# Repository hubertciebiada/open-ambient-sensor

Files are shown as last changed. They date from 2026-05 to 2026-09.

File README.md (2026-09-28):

<h1 align="center">OAS — Open Ambient Sensor</h1>

<p align="center">
  <b>DIY multi-sensor environmental monitor for indoor spaces.</b><br>
  Measures air quality and presence; mounts on a standard wall-recessed electrical box; runs ESPHome and integrates natively with Home Assistant.
</p>

<p align="center">
  
  
  
  
  
</p>

https://github.com/user-attachments/assets/d60150c3-3ed5-4fff-b437-b9b54c48e413

<p align="center">
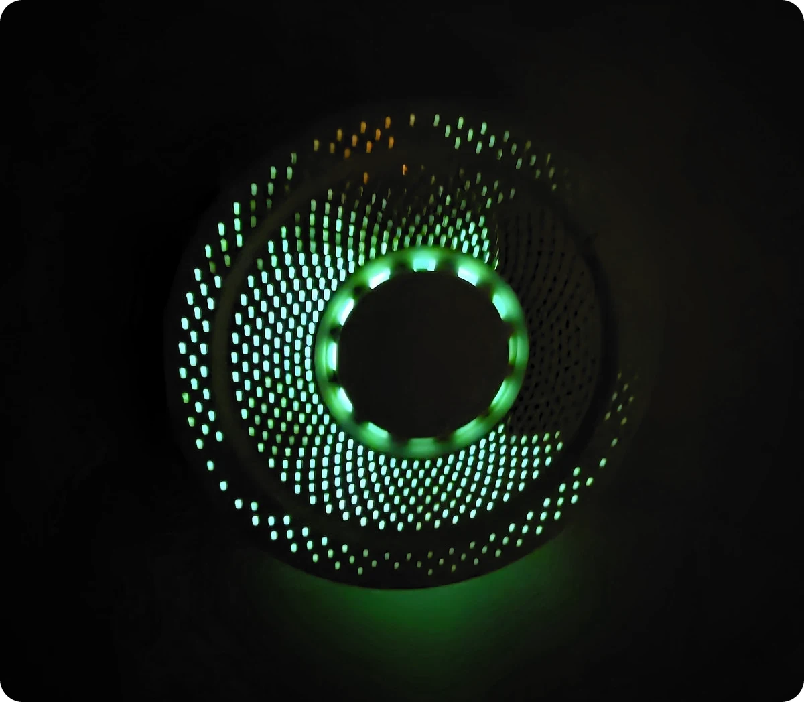
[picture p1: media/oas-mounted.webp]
OAS mounted on a wall in the dark: the AQI ring glows green through the perforated AK-N-94 cover
  
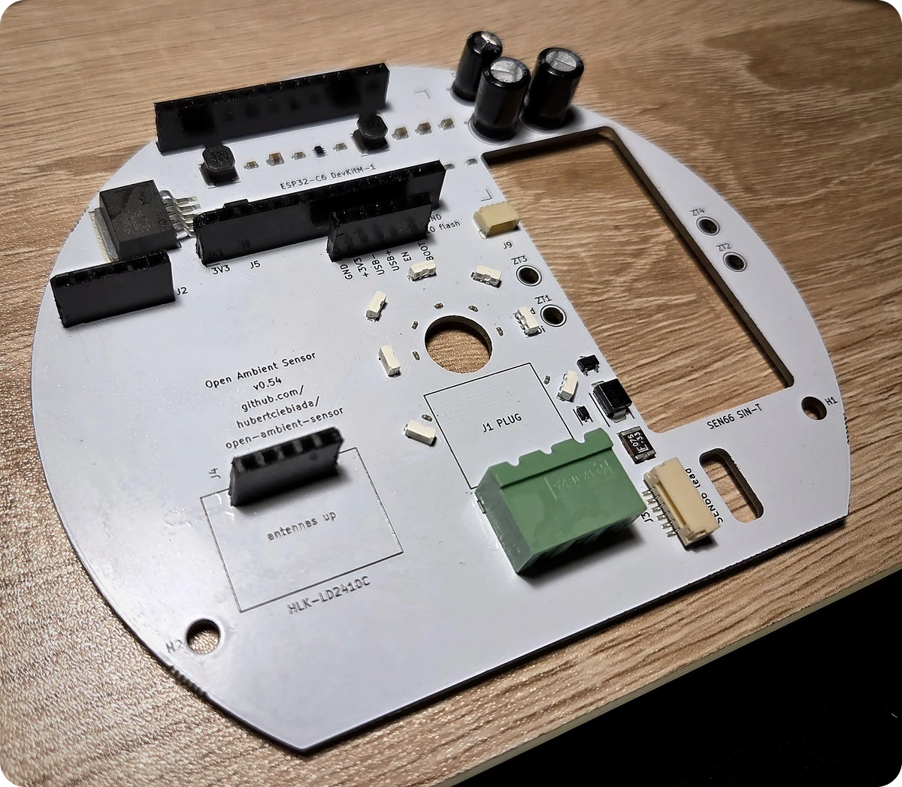
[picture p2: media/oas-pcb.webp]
OAS v0.54 PCB after SMT assembly, THT parts hand-soldered, daughterboards not yet fitted
  
</p>

---

## Status

**v0.54 — manufactured, bench-validated and in use.** Boards of this revision were fabricated and SMT-assembled at JLCPCB, brought up on the bench with a repeatable per-unit check, and run in a multi-unit deployment as the sensor input for Home Assistant HVAC automations. Working on the delivered hardware: the 24 V power chain, the Sensirion SEN66 (CO₂ / PM / VOC / NOx / T / RH, with Sensirion's STAR temperature compensation running inside the module), the HLK-LD2410C presence radar including stillness detection, the LED ring, Wi-Fi / OTA / native Home Assistant API, the Bluetooth proxy and the on-device web dashboard. The firmware reports `project_version: v0.54`, matching the version printed on the silkscreen. The design is fully script-generated and verified: `build.py` 35/35 stages PASS, DRC 0 violations / 0 unconnected, JLCPCB DFM 0 Danger on both the bare-board and assembly checks. The production files for this revision are attached to the [GitHub release](https://github.com/hubertciebiada/open-ambient-sensor/releases). See [`CLAUDE.md`](./CLAUDE.md) for the design rationale, hard constraints and the lessons learned along the way.

---

## Can I build one today?

**Yes — this revision has been built and works.** What to know before ordering:

- **The production files are in the repo.** [`hardware/output/jlcpcb/`](./hardware/output/jlcpcb/) holds the gerber + drill bundle, the BOM and the CPL files for JLCPCB SMT assembly (also attached to the GitHub release); they are regenerated and verified by the 35-stage pipeline on every build. Follow the ordering workflow in [`CLAUDE.md`](./CLAUDE.md#jlcpcb-ordering-workflow-distilled-from-v040-saga) — in particular the pre-payment Assembly Order cross-check, which has caught wrong-part substitutions more than once.
- **Seven components are hand-soldered after assembly** — the 24 V terminal block, the two ESP32-C6-DevKitM-1 socket headers, the LD2410C header and the three THT capacitors — and the SEN66 is attached with its JST GH lead and zip ties. Flashing and Home Assistant onboarding are documented in [`firmware/README.md`](./firmware/README.md).
- **Cost positioning.** OAS deliberately sits above bargain-DIY BOM cost: a calibrated Sensirion SEN66 combo sensor, an mmWave radar with stillness detection, and a commercial-grade injection-moulded enclosure are all premium choices made on purpose — see [Design philosophy](#design-philosophy). If lowest possible cost is your priority, other open-source projects optimise for that instead.

**Known limitations** (findings on the built units):

- **The LED ring effect is weaker than designed.** For the SEN66 to read correctly inside the enclosure, an air duct has to guide room air from the perforated cover to the sensor inlet, and that duct sits in front of part of the ring. The duct is not part of this repository yet.
- **Detecting a sleeping person relies on the presence timeout**, not on the radar's still-target thresholds — see the notes in [`firmware/esphome/packages/presence.yaml`](./firmware/esphome/packages/presence.yaml).
- **v0.51 prototype boards** need the pin overrides in [`firmware/esphome/HARDWARE-COMPAT-v0.51.md`](./firmware/esphome/HARDWARE-COMPAT-v0.51.md); v0.54 boards run the firmware defaults.

A consolidated step-by-step build guide is not written yet; open work is tracked in the [TODO list](./CLAUDE.md#open-work--todo) in `CLAUDE.md`.

---

## What it measures

- **Air quality** — CO₂, PM1 / PM2.5 / PM4 / PM10, VOC index, NOx index, temperature, relative humidity (Sensirion SEN66)
- **Occupancy / presence** — mmWave radar with stillness detection (HiLink HLK-LD2410C)

## Additional features

- 7× SK6812-SIDE RGB AQI ring with breathing effect (7 LEDs on an 8-slot ring; D13 vacated for the J1 24 V terminal); colour reflects an aggregated air-quality index
- **Bluetooth proxy** — extends BLE range across the deployment for Home Assistant BLE integrations
- Qwiic / STEMMA QT expansion port — future sensors without a PCB respin

---

## Design philosophy

The open-source DIY space offers many indoor-air-quality projects. Most optimise aggressively for cost. **OAS holds two priorities non-negotiable**, even when the trade-off is a higher per-unit BOM than the cheapest alternatives:

1. **Measurement quality.** Sensor choices favour accuracy and long-term stability over price.
2. **Aesthetic acceptability.** The device is meant to live in inhabited rooms; a commercial-grade injection-moulded enclosure replaces the typical 3D-printed box.

Both compromises (cheap-but-inaccurate, accurate-but-ugly) are rejected. See [`CLAUDE.md`](./CLAUDE.md) for the full rationale and the hard constraints any change must clear.

---

## Hardware overview

| Function | Component | Interface |
|---|---|---|
| MCU | ESP32-C6-DevKitM-1-N4 (EAN 5904422385651) | 2× USB-C on module |
| Air quality combo | Sensirion SEN66-SIN-T | I²C (JST GH 6-pin cable) |
| Presence | HiLink HLK-LD2410C | UART @ 256000 baud |
| Visual indicator | 7× SK6812-SIDE side-emit ring (Ø26 mm base pitch, 8 slots with D13 vacated for J1) | 1-wire WS281x on GPIO 8 |
| Power input | 24 V DC terminal block + TVS + PTC + reverse-polarity P-FET | — |

**Enclosure:** SZOMK AK-N-94 (Ø128 mm perforated white ABS). PCB is a **Ø120 mm D-shape** with a flat chord along the bottom edge. Mounts on a standard wall-recessed electrical box (60 mm screw pitch).

Authoritative module metadata (EAN, MPN, datasheet URLs, derived dimensions) lives in [`hardware/kicad/boardgen/_project.py::EXTERNAL_MODULES`](./hardware/kicad/boardgen/_project.py). Pinout is in [`boardgen/_project.py::GPIO_ASSIGNMENTS`](./hardware/kicad/boardgen/_project.py). Full design rationale and hard constraints: [`CLAUDE.md`](./CLAUDE.md).

---

## Repository layout

```
open-ambient-sensor/
├── README.md                       # this file
├── CLAUDE.md                       # design rationale, hard constraints, working conventions
├── GPLv3-LICENSE.md
├── .gitignore
├── media/                          # promo video (oas-promo.mp4) + README photos (oas-*.webp)
├── firmware/
│   ├── README.md                   # flashing + Home Assistant integration
│   ├── esphome/
│   │   ├── oas.yaml                # top-level ESPHome config
│   │   ├── packages/               # core / leds / air-quality / presence / bt-proxy
│   │   └── examples/               # anonymized per-device override examples
│   ├── tools/                      # bringup_check.py — repeatable per-unit bench check
│   └── secrets.yaml.example
└── hardware/
    ├── kicad/
    │   ├── build.py                # THE single entrypoint — emits sources + runs the 35-stage pipeline
    │   ├── boardgen/               # source of truth — generators for every .kicad_* file
    │   ├── pipeline/               # 35 verification/export stages (generic / oas / jlcpcb)
    │   ├── tests/                  # unit-test suite (pytest; run by stage 16 of build.py)
    │   ├── tools/                  # manual-trigger scripts (route extract, DFM upload, jlcparts cache)
    │   ├── oas_routes.py           # routing snapshot (replayed onto the generated PCB)
    │   ├── lcsc_mapping.py         # SMD BOM — LCSC SKU source of truth
    │   └── oas.kicad_*             # generated KiCad project files (derived artefacts — never hand-edit)
    ├── renders/                    # generated previews (PNG + SVG, visual changelog)
    ├── photos/                     # photos of built units (EXIF stripped)
    └── output/                     # production deliverables (ibom + jlcpcb/ ZIP + BOM + 2× CPL)
```

---

## Rebuilding the design from source

The KiCad project is **fully script-generated**. The `.kicad_pcb` / `.kicad_sch` / `.kicad_pro` / library files are derived artefacts — **never hand-edit them**; the next build overwrites every edit. The source of truth lives in [`hardware/kicad/boardgen/`](./hardware/kicad/boardgen/) (Python generators), [`lcsc_mapping.py`](./hardware/kicad/lcsc_mapping.py) (SMD BOM), and [`oas_routes.py`](./hardware/kicad/oas_routes.py) (routing snapshot).

```sh
cd hardware/kicad
python build.py
```

`build.py` is the only top-level entrypoint. It regenerates every KiCad source file bit-identically (deterministic v5 UUIDs — an unchanged tree produces an empty `git diff`) and then runs the full 35-stage verification pipeline: DRC, ERC, determinism self-check, analytical DC / ampacity / boot-strap / thermal / I²C-rise-time checks, ngspice SPICE simulations (buck soft-start, IEC 61000-4-5 surge, reverse polarity), unit tests, renders, and the vendor export stages that produce the JLCPCB deliverables. Any stage failure aborts the build.

**Requirements:**

- Python 3.11+
- KiCad 10 with `kicad-cli` on `PATH`
- `pip install mypy pytest cairosvg pygerber`
- `git submodule update --init` (kicad-skip, InteractiveHtmlBom, jlcparts, and other tools under `hardware/kicad/third_party/`)
- One-time jlcparts offline cache for the LCSC part-verification stage: `python hardware/kicad/tools/setup_jlcparts_cache.py` (~2 GiB download, expands to a local SQLite cache)

ngspice and the vendor SPICE models are downloaded automatically into a gitignored `.tmp/` directory on first run. Individual pipeline stages are independently runnable for debugging (e.g. `python pipeline/generic/03_drc.py`), but a committable state always comes from a full `build.py` pass.

---

## Contributing

Contributions are welcome once the design stabilises. Any change must clear both design pillars (measurement quality, aesthetic acceptability) and the hard constraints listed in [`CLAUDE.md`](./CLAUDE.md#hard-constraints-do-not-violate-without-an-explicit-documented-decision).

**This is a public repository** — see the [public-repository rules](./CLAUDE.md#-public-repository-rules) for the anonymisation and third-party-IP requirements that apply to every committed file.

---

## License

GNU General Public License v3.0 — see [`GPLv3-LICENSE.md`](./GPLv3-LICENSE.md).

---

## References

- AirGradient ONE (open-source inspiration): <https://github.com/airgradienthq/arduino>
- Sensirion SEN66 product page: <https://sensirion.com/products/catalog/SEN66>
- HiLink LD2410 documentation: <https://www.hlktech.net>
- ESPHome documentation: <https://esphome.io>
- JLCPCB component library: <https://jlcpcb.com/parts>

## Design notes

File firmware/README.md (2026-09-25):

# Firmware — ESPHome

OAS runs on **ESPHome** (YAML configuration) and integrates with Home Assistant via the native ESPHome API.

Hardware target: **ESP32-C6-DevKitM-1-N4** (ESP32-C6-MINI-1 SoM, 4 MB flash) on the OAS v0.54 PCB (v0.51 prototype boards need the pin overrides in [`esphome/HARDWARE-COMPAT-v0.51.md`](./esphome/HARDWARE-COMPAT-v0.51.md)). Framework: **esp-idf** (required for BLE proxy memory headroom — `arduino` runs out of IRAM with the C6 + BLE + WiFi + sensors all enabled).

## Layout

```
firmware/
├── esphome/
│   ├── oas.yaml             # top-level config, per-device substitutions
│   ├── packages/
│   │   ├── core.yaml        # WiFi, AP fallback, API, OTA, web_server, time, logger
│   │   ├── oas-dashboard.js # on-device dashboard: foldable cards, settings start folded
│   │   ├── leds.yaml        # SK6812-SIDE AQI ring (7 LEDs on GPIO 8; 8-slot ring with D13 vacated for J1)
│   │   ├── air-quality.yaml # Sensirion SEN66 (I²C 0x6B)
│   │   ├── presence.yaml    # HiLink LD2410 (UART @ 256000 baud)
│   │   └── bt-proxy.yaml    # Bluetooth proxy for Home Assistant
│   └── examples/            # anonymized per-device override examples
├── secrets.yaml.example     # template; copy to secrets.yaml (gitignored)
└── README.md                # this file
```

## Quick start

### 1. Install ESPHome

```bash
pip install esphome
```

Or use the Home Assistant ESPHome add-on, or the [ESPHome web flasher](https://web.esphome.io/) for first flash without a CLI.

### 2. Prepare secrets

```bash
cp firmware/secrets.yaml.example firmware/esphome/secrets.yaml
```

Edit `firmware/esphome/secrets.yaml` and fill in:

- `wifi_ssid` / `wifi_password` — your LAN credentials
- `ap_password` — fallback hotspot password (min 8 chars)
- `api_encryption_key` — generate with `openssl rand -base64 32` (paste the result as the `api_encryption_key` value in `secrets.yaml`)
- `ota_password` — any strong password

`secrets.yaml` is gitignored and must never be committed.

### 3. Set per-device identity

Each physical OAS unit needs a unique `device_id` and `friendly_name`. You have three options:

**Option A — Edit substitutions in `oas.yaml` directly** (fine for a single prototype):

```yaml
substitutions:
  device_id: livingroom
  friendly_name: "Living Room"
```

**Option B — Copy `oas.yaml` to a per-device file** (better for fleets):

```bash
cp firmware/esphome/oas.yaml firmware/esphome/devices/livingroom.yaml
# edit substitutions at the top
esphome run firmware/esphome/devices/livingroom.yaml
```

**Option C — Use the ESPHome dashboard** (Home Assistant add-on): each device gets its own per-device YAML in the dashboard UI; substitutions are editable from the web interface.

### 4. Validate the config (recommended before first flash)

```bash
esphome config firmware/esphome/oas.yaml
```

This catches typos and missing secrets without touching the device.

### 5. First flash (over USB-C)

The ESP32-C6-DevKitM-1-N4 has **two USB-C ports** (labels as printed on the DevKit silkscreen; bench-confirmed on the v0.54 bring-up):

- The port labelled **USB** is the ESP32-C6's native USB-Serial-JTAG (GPIO 12/13). It enumerates as `USB VID:PID=303A:1001`, needs no driver on modern Linux/macOS/Windows, and is where the firmware logger writes (`logger: hardware_uart: USB_SERIAL_JTAG`) — **use this port for logs and for the bring-up check below**.
- The port labelled **UART** goes through the onboard CP2102N USB-UART bridge (Silicon Labs CP210x driver). It flashes fine too, but carries no firmware log.

Either port flashes. Plug in and run:

```bash
esphome run firmware/esphome/oas.yaml
```

ESPHome auto-detects the serial port. Pick it from the menu if prompted.

Alternative for first flash without a local Python install: open <https://web.esphome.io/> in Chrome/Edge, click "Connect", select the OAS device, and upload the compiled `.bin` ESPHome produced. The web flasher uses WebSerial — no driver install needed.

### 6. After first flash

Once the device is on your WiFi, the on-device web dashboard is reachable at:

- `http://oas-<device_id>.local/` (mDNS — works on most modern OSes)
- `http://<device-ip>/` (find the IP in your router admin or in Home Assistant)

The dashboard is **web_server v3** (modern post-2024 ESPHome UI) and supports:

- Live sensor readings (CO2, PM, VOC, NOx, temperature, humidity, presence)
- LED ring controls (on/off, mode, brightness 1-10, night mode with its own brightness and hours, and a status line saying what the ring is doing)
- Number entity sliders to adjust sensor calibration offsets in real time
- Foldable cards: the ones holding settings start folded, so scrolling on a phone cannot drag a slider (see [On-device dashboard layout](#on-device-dashboard-layout))
- Live log viewer
- Read-only Prometheus metrics endpoint at `/metrics` for scraping

All of this works without Home Assistant — useful for first-bringup verification.

### 7. Home Assistant integration

Home Assistant should auto-discover the device via mDNS within ~30 seconds of it joining the LAN. If it doesn't, add it manually:

- **Settings → Devices & Services → Add Integration → ESPHome**
- Host: `oas-<device_id>.local` (or the IP)
- Encryption key: paste the `api_encryption_key` from your `secrets.yaml`

After the initial pairing, all further updates flow over the air via the ESPHome dashboard inside Home Assistant.

### 8. Subsequent updates (OTA)

Once a device is on the network, you don't need USB any more. From any machine on the same LAN:

```bash
esphome run firmware/esphome/oas.yaml --device oas-<device_id>.local
```

Or just press "Update" in the Home Assistant ESPHome dashboard.

**Leave the unit powered for at least a minute after an OTA update.** The firmware runs from two OTA slots with ESP-IDF app rollback enabled: the freshly written app only becomes the permanent choice once it has booted cleanly, and a reset or power cut before that hands the next boot back to the previous firmware — "OTA successful" in the upload log notwithstanding. Bench-confirmed on the v0.54 bring-up (a reset ~30 s after OTA rolled back; the same image left alone for 95 s then booted from the new slot and survived a reset).

## Bench bring-up check (repeatable per unit)

`firmware/tools/bringup_check.py` turns "flash it and look at the log" into one command with a PASS/FAIL table, so every assembled board gets the same inspection:

```bash
python firmware/tools/bringup_check.py firmware/esphome/devices/<unit>.yaml
```

Connect the unit to 24 V and the DevKit's **USB** port, then run it. The script finds the port, runs `esphome run` (compiles if needed, flashes), pulses a reset and reads the boot log (ESPHome / project version, SEN66 serial + firmware, STAR preset upload, WiFi, no errors or reboot loop), resolves the unit over mDNS, and reads the web dashboard's event stream to check the live entities: SEN66 readings in sane windows, LD2410 UART alive (distance sensors + baud), the OUT-pin entity, ring, BLE proxy, RSSI. It prints the WiFi MAC + IP (reserve them in DHCP before the unit moves to its room) and writes the full report under `devices/reports/` (gitignored). `--no-flash` re-checks a running unit; `--ip` is the fallback when mDNS does not cross your VLANs.

Note for the bench: until a unit is paired with Home Assistant, `api.reboot_timeout` (15 min) restarts it every 15 minutes with `[E][api]: No clients; rebooting` — expected, and the check ignores that line.

## First-time WiFi provisioning without secrets.yaml

If you don't want to write WiFi credentials into `secrets.yaml` before first flash (e.g. for a unit you're shipping to someone else), the `core.yaml` package enables **Improv Serial**:

1. Flash the device once with placeholder WiFi credentials (any string).
2. Plug it into a host running Chrome/Edge.
3. Visit <https://www.improv-wifi.com/>, click "Connect", select the device.
4. Enter the target SSID + password — the device commits them to flash and reboots onto WiFi.

Alternatively, the **AP fallback** (`OAS-<device_id>-Setup` SSID, gated by `ap_password`) and **captive portal** combination lets a phone connect to the device's own hotspot and re-enter credentials through a web form.

## Troubleshooting

| Symptom | Likely cause |
|---|---|
| Device doesn't show up on mDNS | Most consumer routers block mDNS across VLANs. Find the IP via your router admin and use `http://<ip>/` directly. |
| `secrets.yaml not found` | The file lives next to `oas.yaml`, i.e. `firmware/esphome/secrets.yaml`, not at the repo root. |
| `Could not find file '…/firmware/packages/oas-dashboard.js'` | ESPHome older than 2026.9 compiling `oas.yaml` directly: before 2026.9 a package's file paths resolve only relative to the main config, and the path in `core.yaml` is written for a config one level down (`devices/`, `examples/`). Update ESPHome, or compile through a per-device file in `devices/`. |
| OTA fails with "wrong password" | Re-flash via USB-C with the new password baked in. Lost OTA passwords cannot be recovered. |
| LED ring doesn't light | Check that `+5V` is reaching the LM2596S output — `core.yaml` itself never touches the LED ring; that's `leds.yaml`'s job. |
| SEN66 measurements stuck on "unavailable" | Likely I²C bus issue; scan with `i2c.scan: true` (already enabled). SEN66 lives at 0x6B. |
| Presence flips on/off every few seconds in an empty room | Gate 0 (0-0.75 m) picking up the SEN66 fan / cover from inside the enclosure on the factory threshold (moving energy 51-55 vs 50, reported distance ~30 cm). Set `G0 Move Threshold` to 100 (`bringup_check.py` does it on every unit), then press `LD2410 Read Params` to confirm the radar stored it. |
| LD2410 presence never triggers | Verify UART pins (TX=GPIO1, RX=GPIO0 — they moved off GPIO16/17, see CLAUDE.md Lesson 23) and 256000 baud rate. Use `logger: VERBOSE` to see the raw protocol. |

## Status

**Firmware v0.54 — running on the v0.54 boards (5 packages):** `core.yaml`, `leds.yaml`, `air-quality.yaml`, `presence.yaml`, `bt-proxy.yaml`. Bench-validated on delivered hardware: SEN66 readings with Sensirion's STAR temperature compensation inside the module, LD2410C presence over UART (per-gate thresholds, gate 0 disabled, the radar's Bluetooth kept off), LED ring, OTA through the Home Assistant ESPHome add-on, native API discovery, Bluetooth proxy. `project_version` follows the board silkscreen (`v0.54`). `tools/bringup_check.py` is the repeatable per-unit bench check. The dynamic NFC tag package was removed together with the NFC hardware (GitHub issue #7).

---

## Home Assistant integration

### Exposed entities

#### Sensors (`sensor.*`)

| Entity (suffix) | Unit | Source |
|---|---|---|
| `co2` | ppm | SEN66 (NDIR, 400-40 000 ppm) |
| `pm1` / `pm2_5` / `pm4` / `pm10` | µg/m³ | SEN66 (laser scatter) |
| `voc_index` | (1-500) | SEN66 MOX (Sensirion VOC index, 100 = baseline) |
| `nox_index` | (1-500) | SEN66 MOX (1 = baseline) |
| `temperature` | °C | SEN66 SHT4x (STAR-Engine compensated) |
| `humidity` | %RH | SEN66 SHT4x |
| `presence_distance` | cm | LD2410 (0-600 cm, ~100 ms cadence) |
| `moving_target_energy` / `still_target_energy` | (0-100) | LD2410 radar return amplitude |
| `wifi_rssi` | dBm | ESPHome built-in |
| `uptime` | s | ESPHome built-in |

#### Binary sensors (`binary_sensor.*`)

| Entity (suffix) | Source |
|---|---|
| `presence` | LD2410 OUT pin (GPIO 2) — hardware-level flag, fastest path |
| `moving_target` / `still_target` | LD2410 protocol |
| `api_connected` | ESPHome (true when API paired with HA) |

#### Light, numbers, selects, text, buttons, switches

- `switch.ring`, `select.ring_mode` (`AQI Breathing` / `AQI Solid` / `Dot Chase`), `number.ring_brightness` (1-10), `switch.ring_night_mode`, `number.ring_night_brightness` (0 up to the ring brightness), `time.ring_night_start` / `time.ring_night_end` — the AQI ring (7 × SK6812-SIDE), the same seven controls as the dashboard's LED ring card, all under the device's *Configuration*; see [LED ring](#led-ring) below. There is no `light` entity (the light is internal to the firmware), and the Ring Status line is dashboard-only
- `number.temperature_offset` / `number.temperature_offset_tau` and `number.temperature_offset_slow` / `number.temperature_offset_slow_tau` — SEN66 STAR-Engine offset slots 0 and 1 (°C, s), written into the module at boot and on every change; RH follows automatically (see "SEN66 temperature compensation" below). `number.humidity_offset` (-20..+20 %RH), `number.co2_offset` (-100..+100 ppm) — ESPHome-side trims on the published value
- `number.max_move_gate` / `number.max_still_gate` (2-8 gates × 0.75 m), `number.presence_timeout` (0-65535 s), `number.g<0-8>_move_threshold` / `number.g<0-8>_still_threshold` (0-100 per gate, 100 disables the gate; stored in the radar's own flash). Gate 0 (0-0.75 m) sees the SEN66 fan and the cover from inside the enclosure and flaps on the factory threshold, so the bring-up script disables it — see the note in `packages/presence.yaml`
- `button.restart` / `button.sen66_force_clean` / `button.ld2410_factory_reset`
- `switch.bluetooth_proxy` (default on) / `switch.prevent_sleep`
- `text_sensor.star_engine_state` — what the boot sequence sent to the SEN66 STAR-Engine, the I2C result and the warm/cold-start decision (e.g. `downtime 8 s, f0 1.00, f1 1.00`); `text_sensor.reset_reason` — ESP32 reset reason (input for that decision)

### SEN66 temperature compensation (STAR-Engine)

Inside the enclosure the SEN66 sits behind the regulators, the ESP32-C6 and the radar and reads a few kelvin above the room. The firmware compensates this the way Sensirion prescribes in the *SEN6x Temperature Acceleration and Compensation Instructions* (app note v1.1, 01/2026, Downloads on the SEN66 product page): inside the module, not with an ESPHome filter.

- **Acceleration** (I2C 0x6100): the "Light / IAQM" preset from the app note (T1 100 s, T2 300 s, K 20, P 20). The command is idle-only and volatile, so the boot sequence stops the measurement, writes it and restarts; the component ignores the first 60 s of readings anyway.
- **Offset slots** (I2C 0x60B2, volatile, additive to the factory self-heating compensation): slot 0 = the enclosure over-temperature with its warm-up time constant, slot 1 = an optional slower second exponential (foam gasket, enclosure). The values live in the `number.temperature_offset*` entities (NVS-persisted, defaults in `packages/air-quality.yaml`) and are re-sent at every boot. After any reset but a power-on (OTA, restart, watchdog, brownout) the ESP never lost power, the enclosure is warm and they apply at once. After a power-on the unit works out how long it was off: it stamps the network time into flash once a minute, and at boot it waits for the clock (up to 60 s of uptime) to get the downtime d. The enclosure still holds f = e^(−d/τ) of each offset, so that part applies at once and the rest ramps in with τ: a few-second 24 V interruption comes back almost fully compensated (f ≈ 1), a night off ramps in from zero as before (f ≈ 0). No clock within 60 s, or no stamp yet (first boot of this firmware) → a power-on counts as a cold start. *STAR-Engine State* shows the case and d / f. The module recomputes RH from the corrected temperature, so RH needs no separate offset.
- **Why the downtime matters**: before this, every power-on took the cold path, so a few-second interruption on a warm unit read up to ~3 K high for about one τ (~2.9 K at the peak on the reference unit), long enough for climate automations to act on it.
- **Deriving the values** (app note §2.2, the "basic" recipe): two reference thermometers next to the unit, room steady, no air conditioning. Offset = T_reference − T_module averaged over the last hour of a steady state (negative when the unit reads warm). Tau = time from a cold power-on (unit off for at least 3–4 h) until the module temperature crosses 63 % of its final over-temperature. Set both offsets to 0 before the cold start so the recording is the bare module output, then enter the results in Home Assistant. The reference unit (AK-N-94, foam gasket on the SEN66, ring 25 % = Ring Brightness 4, the default, BLE proxy on) came out at −3.4 K; any change to the heat budget shifts it, so re-check after hardware or power-state changes.
- **Slope** (offset vs room temperature) stays 0 until a second temperature level is measured — see the `TODO (winter)` note at the top of `packages/air-quality.yaml`.
- There is no read-back command for either register, so verify against a reference thermometer, not the text sensor.

### On-device dashboard layout

The web dashboard at `http://<device-ip>/` groups its entities into six cards (web_server v3 sorting groups, declared in `packages/core.yaml`, one `web_server:` key per entity in the package that owns it): **Air quality** and **Air quality - settings**, **Presence** and **Presence - settings**, **LED ring**, and **System** for what belongs to the ESP32 itself (radio, uptime, reset reason, BLE proxy, service buttons). Measurements are separated from the settings that shape them, so a card answers either "what does it read" or "how is it tuned". Home Assistant ignores the grouping and sorts by `entity_category` instead.

Tap a card's title to fold or unfold it. Every time the page opens, **Air quality** and **Presence** — the cards that hold nothing but readings — are open, and every card with something you can change or with diagnostics (the two settings cards, LED ring, System) starts folded, showing only its title and how many entries it holds. So a thumb scrolling the page on a phone cannot drag a threshold slider or hit *Restart* by accident: open the card when you mean to change something. What you fold or unfold stays that way until the page is reloaded. The folding is `packages/oas-dashboard.js`, served with the page (`web_server: js_include` in `core.yaml`); it decides from the entities themselves, so a card added later follows the same rule.

### Dashboard idea (starter Lovelace card)

```yaml
type: vertical-stack
title: Living Room
cards:
  - type: glance
    entities:
      - { entity: sensor.oas_livingroom_co2, name: CO₂ }
      - { entity: sensor.oas_livingroom_pm2_5, name: PM2.5 }
      - { entity: sensor.oas_livingroom_temperature, name: Temp }
      - { entity: sensor.oas_livingroom_humidity, name: RH }
      - { entity: binary_sensor.oas_livingroom_presence, name: Presence }
  - type: gauge
    entity: sensor.oas_livingroom_co2
    min: 400
    max: 2500
    severity: { green: 400, yellow: 900, red: 1400 }
    name: CO₂ (ppm)
  - type: history-graph
    title: Air quality (24 h)
    entities:
      - sensor.oas_livingroom_co2
      - sensor.oas_livingroom_voc_index
      - sensor.oas_livingroom_pm2_5
    hours_to_show: 24
```

### Sample automation: ventilate on high CO₂

```yaml
trigger:
  - platform: numeric_state
    entity_id: sensor.oas_livingroom_co2
    above: 1200
    for: "00:05:00"
action:
  - service: switch.turn_on
    target: { entity_id: switch.bedroom_ventilator }
```

The 5-minute `for:` debounces brief CO₂ spikes (someone exhaling on the device).

### LED ring

The ring shows the air quality on its own, without any Home Assistant wiring: green → yellow → orange → red → purple as the AQI rises. The dashboard's *LED ring* card lists its settings in this order:

| # | Setting | Range | What it does |
|---|---|---|---|
| 1 | **Ring** | on / off | The ring's own switch. Nothing else turns it on |
| 2 | **Ring Mode** | `AQI Breathing` / `AQI Solid` / `Dot Chase` | Slow swell in the AQI colour (default), the AQI colour held steady, or a rotating white dot |
| 3 | **Ring Brightness** | 1-10 | The LEDs' full range in ten even steps (default 4) |
| 4 | **Ring Night Mode** | on / off | Use the night brightness inside the night window (default on) |
| 5 | **Ring Night Brightness** | 0 up to Ring Brightness | Brightness at night (default 1). **0 = dark for the night**, back on at night end. A value above Ring Brightness snaps back to it, and lowering Ring Brightness pulls it down too |
| 6 | **Ring Night Start / End** | time | The night window (default 22:00 → 07:00, may wrap midnight). The same time twice = no night |
| | **Ring Status** | — | What the ring is doing and until when, e.g. `Day, brightness 4 until 22:00, then 1`. Dashboard only — not a control, so not in Home Assistant |

The brightness steps are LED output 1, 2, 3, 5, 10, 19, 36, 69, 133 and 255 (of 255): each about 1.9× the one below, from the dimmest glow the LEDs can make (1) to full power (10). That replaces the light's own 0-255 slider, whose bottom ~16 % is one and the same dimmest glow on these 8-bit, gamma-corrected LEDs. The light entity itself is internal, so the dashboard and Home Assistant show only the settings above. Brightness 4, the default, is exactly the old 25 % setting the reference unit ran at when the temperature offset was calibrated. At brightness 10 the ring dissipates ~0.2-0.35 W (AQI colours) to ~0.5 W (white) next to the SEN66, which warms its temperature reading — the temperature offset was calibrated with the ring at 4.

At brightness 1-6 the breathing effect uses only colours that keep their hue all the way down the breath: green (AQI up to 89), yellow (90-121) and red (122-200). A breath there bottoms out at 1-3 LED steps, where an LED has no in-between shades, so a mixed colour such as yellow-green or orange cannot dim without changing hue — it would flicker towards red on the exhale. *AQI Solid*, and the breath from brightness 7 up, show the full gradient.

When the air turns critical (AQI > 200 or CO₂ > 1500 ppm), a ring that is on turns solid red — at least brightness 7 by day, the night brightness at night (so it never lights up a sleeping room) — and goes back to its mode when the air clears.

Settings survive reboots and OTA updates; after a restart at night the ring comes up at the night brightness even before the clock syncs.

Home Assistant gets the same seven controls, all in the device page's *Configuration* card (HA sorts them alphabetically there). A card with them in the dashboard's order:

```yaml
type: entities
title: LED ring
entities:
  - switch.oas_livingroom_ring
  - select.oas_livingroom_ring_mode
  - number.oas_livingroom_ring_brightness
  - switch.oas_livingroom_ring_night_mode
  - number.oas_livingroom_ring_night_brightness
  - time.oas_livingroom_ring_night_start
  - time.oas_livingroom_ring_night_end
```

Automations switch the ring with `switch.oas_<device>_ring`. Example — ring off while the room is empty (at night it still follows the night brightness when switched on):

```yaml
trigger:
  - platform: state
    entity_id: binary_sensor.oas_livingroom_presence
    to: "off"
    for: "00:10:00"
    id: empty
  - platform: state
    entity_id: binary_sensor.oas_livingroom_presence
    to: "on"
    id: occupied
action:
  - if:
      - condition: trigger
        id: occupied
    then:
      - service: switch.turn_on
        target: { entity_id: switch.oas_livingroom_ring }
    else:
      - service: switch.turn_off
        target: { entity_id: switch.oas_livingroom_ring }
```

Upgrading from firmware that had *Ring Max Brightness*, *Night Mode* and *Night Mode Start/End Hour*: those entities — and the old `light.oas_<device>_ring` — are gone; remove them from Home Assistant once they show as unavailable. The new settings start at their defaults.

The dashboard shows `internal` entities too (`web_server: include_internal: true` in `core.yaml`) — that is how Ring Status stays out of Home Assistant. The ring's own light entity is internal as well but disabled by default, so it only appears behind the dashboard's *Show All* button; anything changed there is undone by the firmware within a second.

### Bluetooth proxy

`bluetooth_proxy:` is enabled in firmware. In a multi-unit deployment, this gives near-whole-home BLE coverage for HA's BLE integrations (xiaomi_ble plant sensors, govee BLE thermometers, presence beacons) without dedicated proxies. Home Assistant auto-discovers the proxy. Runtime control via `switch.oas_<device>_bluetooth_proxy`.

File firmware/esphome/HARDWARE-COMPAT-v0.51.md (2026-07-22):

# ⚠ Hardware ↔ firmware compatibility — v0.51 boards need pin overrides

The firmware DEFAULTS in `oas.yaml` target boards with the **corrected J3
pinout** (GitHub issue #6 fixed): `i2c_sda_pin: GPIO6` / `i2c_scl_pin: GPIO7`
— the schematic mapping. The five **v0.51** prototype boards (2026-05 run)
have **SDA/SCL crossed at J3** (the SEN66 socket) and MUST be flashed with a
substitution override that swaps the two pins.

They need a **second** override as well: v0.51 routes the LD2410 UART to
GPIO 16/17, which later boards vacated (`ld2410_tx_pin: GPIO1` /
`ld2410_rx_pin: GPIO0` are now the defaults). See "LD2410 UART pins" below.

➡ **Flashing the wrong mapping bricks the SEN66 either way** — the sensor is
powered but never ACKs at 0x6B (`[E][sen6x] Communication failed`, all
channels NA). Match the firmware to the board revision (check the silkscreen
version marking) before flashing.

## Which firmware goes on which board

| Board | J3 pinout | SEN66 cable | I²C substitutions | LD2410 UART substitutions |
|---|---|---|---|---|
| **v0.51** (five 2026-05 protos) | SDA/SCL crossed (error) | straight 1:1 | `i2c_sda_pin: GPIO7` / `i2c_scl_pin: GPIO6` — override, see below | `ld2410_tx_pin: GPIO16` / `ld2410_rx_pin: GPIO17` — override |
| Fixed rev (issue #6 landed) | mirror of SEN6x Table 16 (correct) | straight 1:1 | defaults (`GPIO6` / `GPIO7`) — no override | defaults (`GPIO1` / `GPIO0`) — no override |

## v0.51 override (exact snippet)

Create a per-device config that includes `oas.yaml` as a package and swaps
the pins (complete template: [`examples/v0.51-board.yaml`](examples/v0.51-board.yaml)):

```yaml
substitutions:
  device_id: room-a
  friendly_name: "Room A"
  i2c_sda_pin: GPIO7      # v0.51 board: J3 SDA/SCL crossed (issue #6)
  i2c_scl_pin: GPIO6
  ld2410_tx_pin: GPIO16   # v0.51 board: radar UART still on the console pins
  ld2410_rx_pin: GPIO17
  project_version: "v0.51"

packages:
  oas: !include ../oas.yaml
```

`!secret` resolution: ESPHome searches for `secrets.yaml` next to the file
that uses the tag (`packages/`) or next to the main config (`examples/`) —
NOT next to the packaged `oas.yaml`. Create a one-line uncommitted proxy
`examples/secrets.yaml` (the `**/secrets.yaml` gitignore covers it):

```yaml
<<: !include ../secrets.yaml
```

## Why v0.51 needs the swap (root cause — issue #6, bench-confirmed 2026-06-30)

The v0.51 J3 copied the SEN6x datasheet **Table 16** pinout (v0.92 Dec 2025,
p. 15 — 1=VDD, 2=GND, 3=SDA, 4=SCL, 5=GND, 6=VDD) pin-for-pin onto the
board-side socket. Table 16 is the **module side**. Both cable ends are
polarized JST GH-family connectors (the latch/shroud keying means housing
position N always mates header pin N), and a standard flat parallel-wire GH
lead has both housings crimped on the same face of the wire row — between
two face-to-face headers that maps position k to position 7−k, a full
positional mirror (1↔6, 2↔5, 3↔4). Sensirion's pinout is power-symmetric
(pins 1/6 and 2/5 internally tied), so the mirror is invisible on the power
pins and manifests ONLY as an SDA↔SCL swap: the SEN66 was powered but never
ACKed. Swapping the I²C pins in firmware cancels the board error — bring-up
confirmed the SEN66 then ACKs at 0x6B and reports real readings with a
straight cable (no cable surgery).

The corrected board (issue #6 fix) wires J3 as the MIRROR of Table 16
(1=VDD, 2=GND, **3=SCL, 4=SDA**, 5=GND, 6=VDD) so a straight flat lead lands
SDA→SDA / SCL→SCL and the defaults are correct. See CLAUDE.md **Lesson 21**;
enforced in CI by pipeline stage 19 check E.

Cable caveat (both revisions): the design standardizes on the **flat
parallel-wire** GH lead style — the style verified on the bench. An
opposite-crimp lead (housings on opposite faces of the wire row,
electrically position-1:1 — the Qwiic-cable style) would re-cross SDA/SCL.
Do NOT reuse a hand-crossed cable from the early v0.51 workaround era on a
corrected board (double-cross).

## LD2410 UART pins (v0.51 = GPIO 16/17, later boards = GPIO 1/0)

v0.51 wires J4's UART pair to the ESP32-C6's **U0TXD/U0RXD** (GPIO 16/17).
On the ESP32-C6-DevKitM-1 those two pads are also hard-wired, through
**populated 0 Ω links** (R9 → bridge RXD, R7 → bridge TXD), to the onboard
**CP2102N** USB-UART bridge — and that bridge's VDD/REGIN sit on `VCC_3V3`,
the board 3.3 V rail OAS feeds at J5.1, **not** on USB VBUS. The bridge is
therefore powered and driving whenever the unit is on, cable or no cable:
bench-probed on a v0.51 board (2026-07-22, radar unpowered, bridge USB port
empty) GPIO 17 read **DRIVEN HIGH** while GPIO 2 and GPIO 16 read floating.
The radar's Tx output and the bridge's TXD output share that node.

Later boards move the pair to **GPIO 1 (TX) / GPIO 0 (RX)** — free, adjacent
pads on the socket row nearest J4. See CLAUDE.md **Lesson 23**; enforced in
CI by the console-pin checks in pipeline stage 06.

On a v0.51 board the override restores communication with the module, but
the contention is physical and cannot be fixed in firmware — the presence
`binary_sensor` fed by the radar's **OUT** pin (GPIO 2) is unaffected and
stays the reliable signal there.

## Bus-wide side effect: J9 Qwiic port

The I²C mapping is bus-wide, so it also affects the J9 Qwiic port:

- corrected board + defaults → J9 is a **standard** Qwiic port;
- v0.51 board + override → a standard Qwiic device on J9 needs a
  **crossed** Qwiic cable.

## Applies to every revision (kept here for history)

- **NFC removed entirely** (issue #7): `packages/nfc.yaml` is gone and the
  MIKROE-2462 / NT3H1101 hardware (MOD2, J7, J8, C12, the NFC_FD net) is
  removed from the corrected board revision. On the five v0.51 boards the
  J7/J8 footprints + MOD2 silk remain physically present but unpopulated.
  With NFC gone the SEN66 is the only fixed I²C device (LD2410 is UART),
  which is why the v0.51 pin-swap override is safe on the shared bus.
- **LED ring `num_leds: 7`** matches every board (D11..D18, D13 skipped).

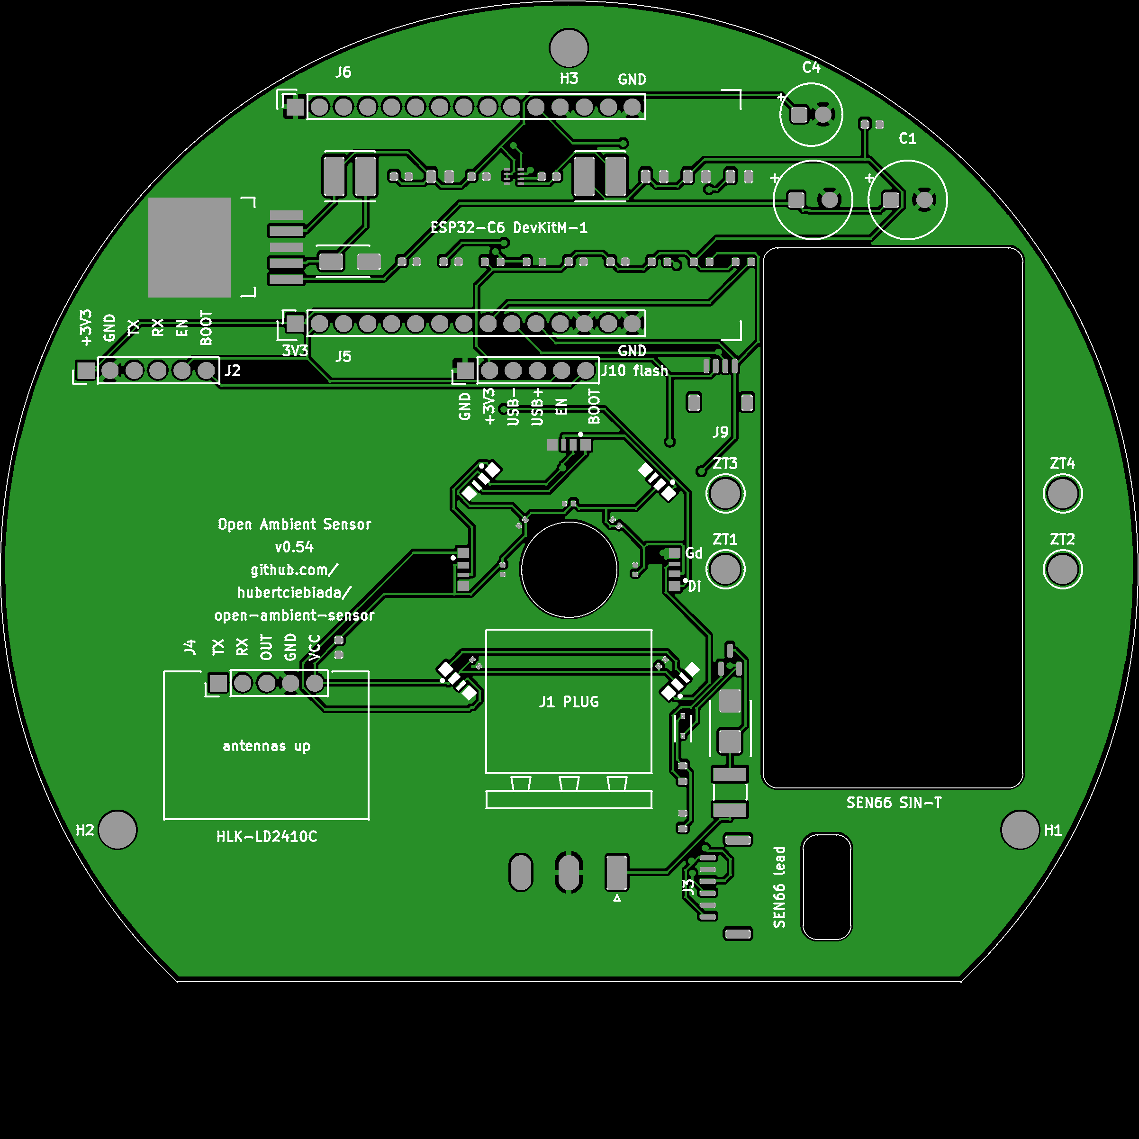
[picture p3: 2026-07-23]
hardware/renders/pcb/preflight-top.png

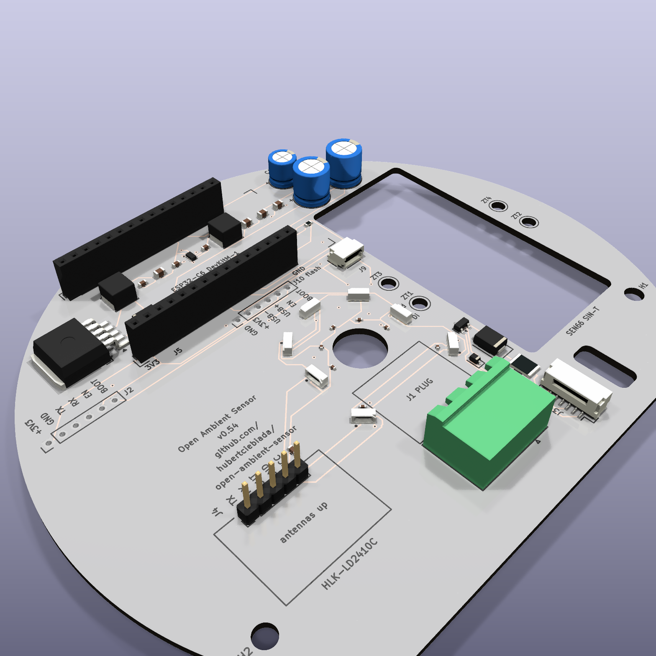
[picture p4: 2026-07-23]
hardware/renders/pcb/3d-iso.png

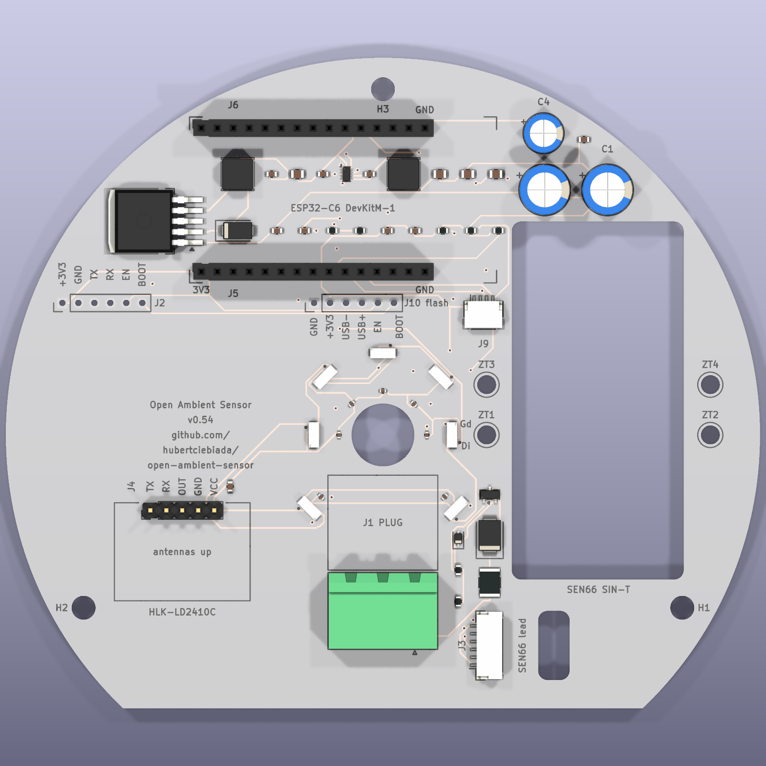
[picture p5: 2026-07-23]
hardware/renders/pcb/3d-top.png

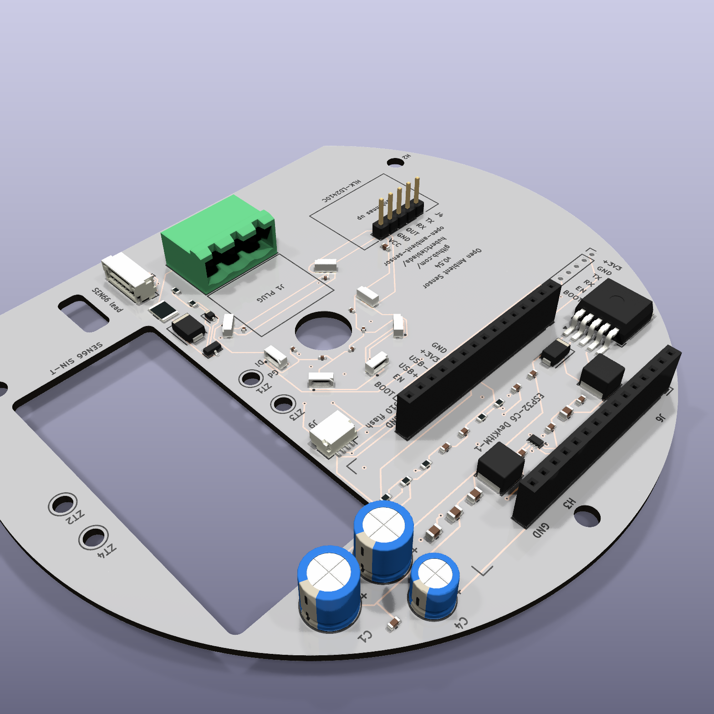
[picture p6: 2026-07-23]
hardware/renders/pcb/3d-iso-180.png

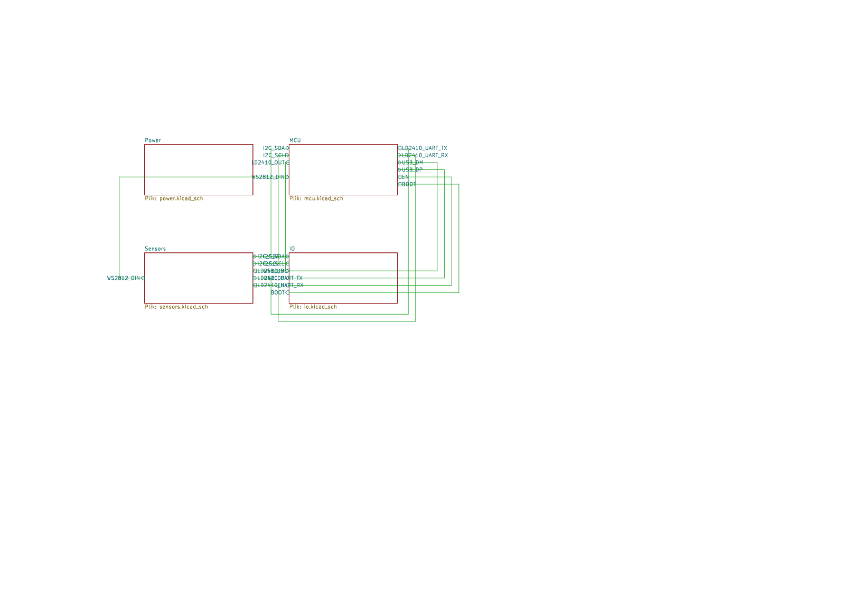
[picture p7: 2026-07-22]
hardware/renders/sch/sch-root.png

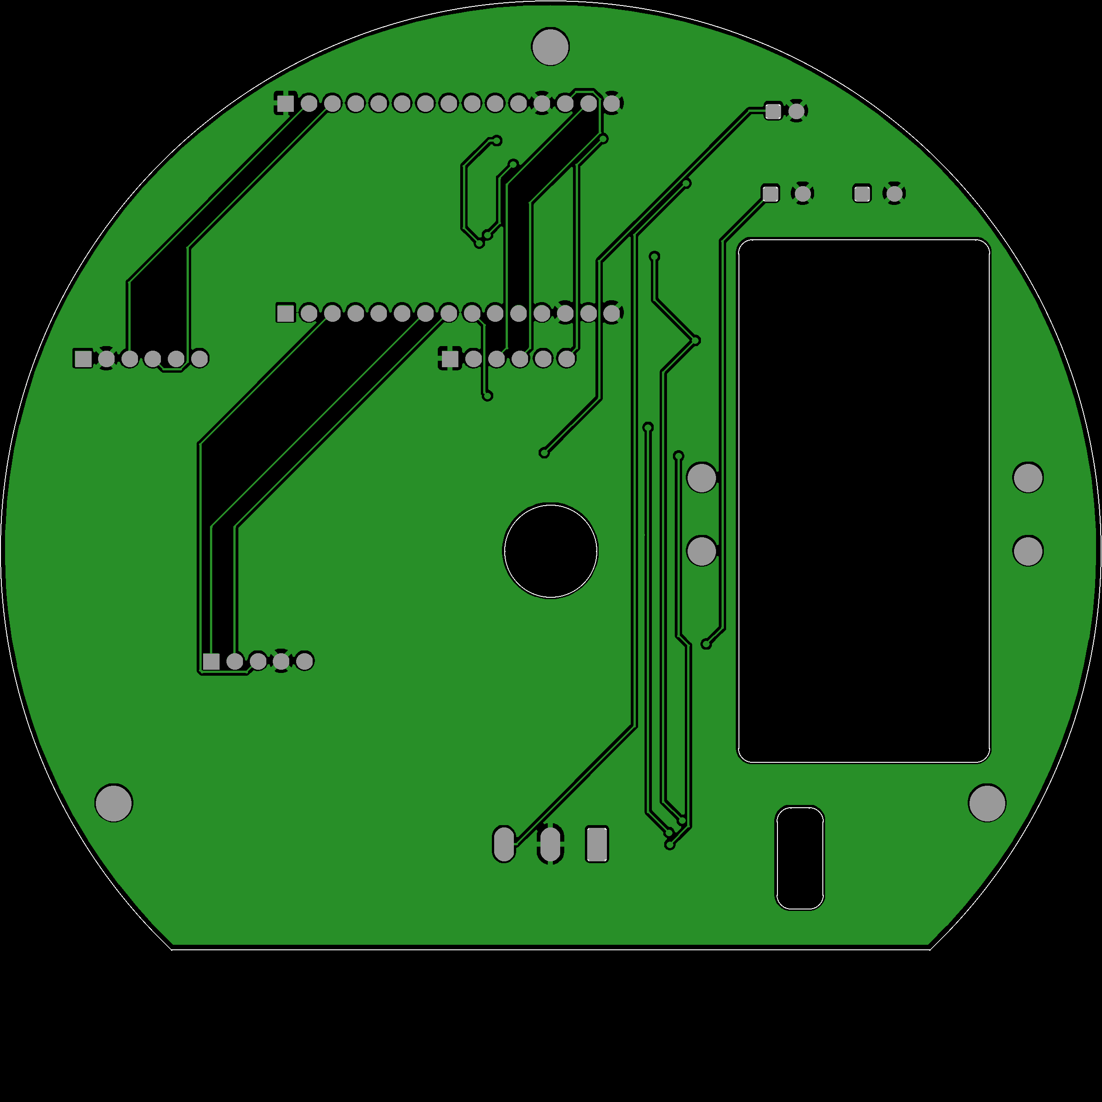
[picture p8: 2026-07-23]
hardware/renders/pcb/preflight-bottom.png

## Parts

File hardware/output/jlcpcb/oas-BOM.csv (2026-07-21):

Comment | Designator | Footprint | Manufacturer | MPN | LCSC Part # | JLCPCB_Library | Qty
47nF | C8 | C_0603_1608Metric | Samsung Electro-Mechanics | CL10B473KB8NNNC | C1622 | Basic | 1
100nF | C7,C10,C11,C13,C14,C15,C16,C17 | C_0603_1608Metric | Yageo | CC0603KRX7R9BB104 | C14663 | Basic | 8
100nF | C20,C21,C23,C24,C25,C26,C27 | C_0402_1005Metric | Samsung Electro-Mechanics | CL05B104KO5NNNC | C1525 | Basic | 7
1k | R4 | R_0603_1608Metric | UNI-ROYAL (Uniroyal Elec) | 0603WAF1001T5E | C21190 | Basic | 1
100k 1% | R1,R2 | R_0603_1608Metric | UNI-ROYAL (Uniroyal Elec) | 0603WAF1003T5E | C25803 | Basic | 2
100uF 50V | C1,C3 | CP_Radial_D8.0mm_P3.50mm |  |  |  | THT (hand-solder) | 2
10k 1% | R7 | R_0603_1608Metric | UNI-ROYAL (Uniroyal Elec) | 0603WAF1002T5E | C25804 | Basic | 1
10nF Y2 | C2 | C_0805_2012Metric | Murata Electronics | GRM21BR72A103KA01L | C97925 | Extended | 1
10uF 25V | C5,C9 | C_0805_2012Metric | Samsung Electro-Mechanics | CL21A106KAYNNNE | C15850 | Basic | 2
10V Zener 200mW | D3 | D_SOD-323 | Nanjing Semtech Electronics | BZT52C10S | C19334 | Extended | 1
1x15 P2.54 mm female socket (ESP32 J1 antenna-side row) | J5 | PinSocket_1x15_P2.54mm_Vertical |  |  |  | THT (hand-solder) | 1
1x15 P2.54 mm female socket (ESP32 J3 USB-side row) | J6 | PinSocket_1x15_P2.54mm_Vertical |  |  |  | THT (hand-solder) | 1
1x5 P2.54mm through-hole header (HLK-LD2410C daughterboard, soldered) | J4 | PinHeader_1x05_P2.54mm_Vertical |  |  |  | THT (hand-solder) | 1
2.2uH 2A | L2 | L_Cenker_CKCS5040 | CENKER | CKCS5040-2.2uH/M | C354602 | Extended | 1
220uF 10V | C4 | CP_Radial_D6.3mm_P2.50mm |  |  |  | THT (hand-solder) | 1
22uF 10V | C6 | C_0805_2012Metric | Samsung Electro-Mechanics | CL21A226MAQNNNE | C45783 | Basic | 1
30.9k 1% | R3 | R_0603_1608Metric | UNI-ROYAL (Uniroyal Elec) | 0603WAF3092T5E | C23022 | Extended | 1
33uH 2A | L1 | L_Cenker_CKCS5040 | CENKER | CKCS5040-33uH/M | C354612 | Extended | 1
4.7k 1% | R5,R6 | R_0603_1608Metric | UNI-ROYAL (Uniroyal Elec) | 0603WAF4701T5E | C23162 | Basic | 2
AO3401A | Q1 | SOT-23 | Alpha & Omega Semiconductor | AO3401A | C15127 | Extended | 1
JST SH SM04B-SRSS-TB (Qwiic / Stemma QT) | J9 | JST_SH_SM04B-SRSS-TB_1x04-1MP_P1.00mm_Horizontal | JST Sales America | SM04B-SRSS-TB(LF)(SN) | C160404 | Extended | 1
JST SM06B-GHS-TB (SEN66-SIN-T, MPN 3.001.030; TME/Mouser) | J3 | JST_GH_SM06B-GHS-TB_1x06-1MP_P1.25mm_Horizontal | JST Sales America | SM06B-GHS-TB(LF)(SN) | C133065 | Extended | 1
LM2596S-5.0 | U1 | TO-263-5_LM2596 | Texas Instruments | LM2596S-5.0/NOPB | C116713 | Extended | 1
Phoenix_MSTBA_2,5/3-G-5,08 | J1 | PhoenixContact_MSTBA_2,5_3-G-5,08_1x03_P5.08mm_Horizontal |  |  |  | THT (hand-solder) | 1
PTC 750mA / 33V | F1 | Fuse_1812L_4532Metric | Littelfuse | 1812L075/33DR | C151170 | Extended | 1
SK6812-SIDE | D11,D12,D14,D15,D16,D17,D18 | SK6812-SIDE | OPSCO Optoelectronics | SK6812SIDE-A | C5378721 | Extended | 7
SMBJ24A | D1 | D_SMB | Brightking | SMBJ24A | C87268 | Basic | 1
SS14 | D2 | D_SMA | MDD (Microdiode Semiconductor) | SS14 | C2480 | Basic | 1
TPS62933 | U2 | SOT-583-8 | Texas Instruments | TPS62933DRLR | C3200405 | Extended | 1

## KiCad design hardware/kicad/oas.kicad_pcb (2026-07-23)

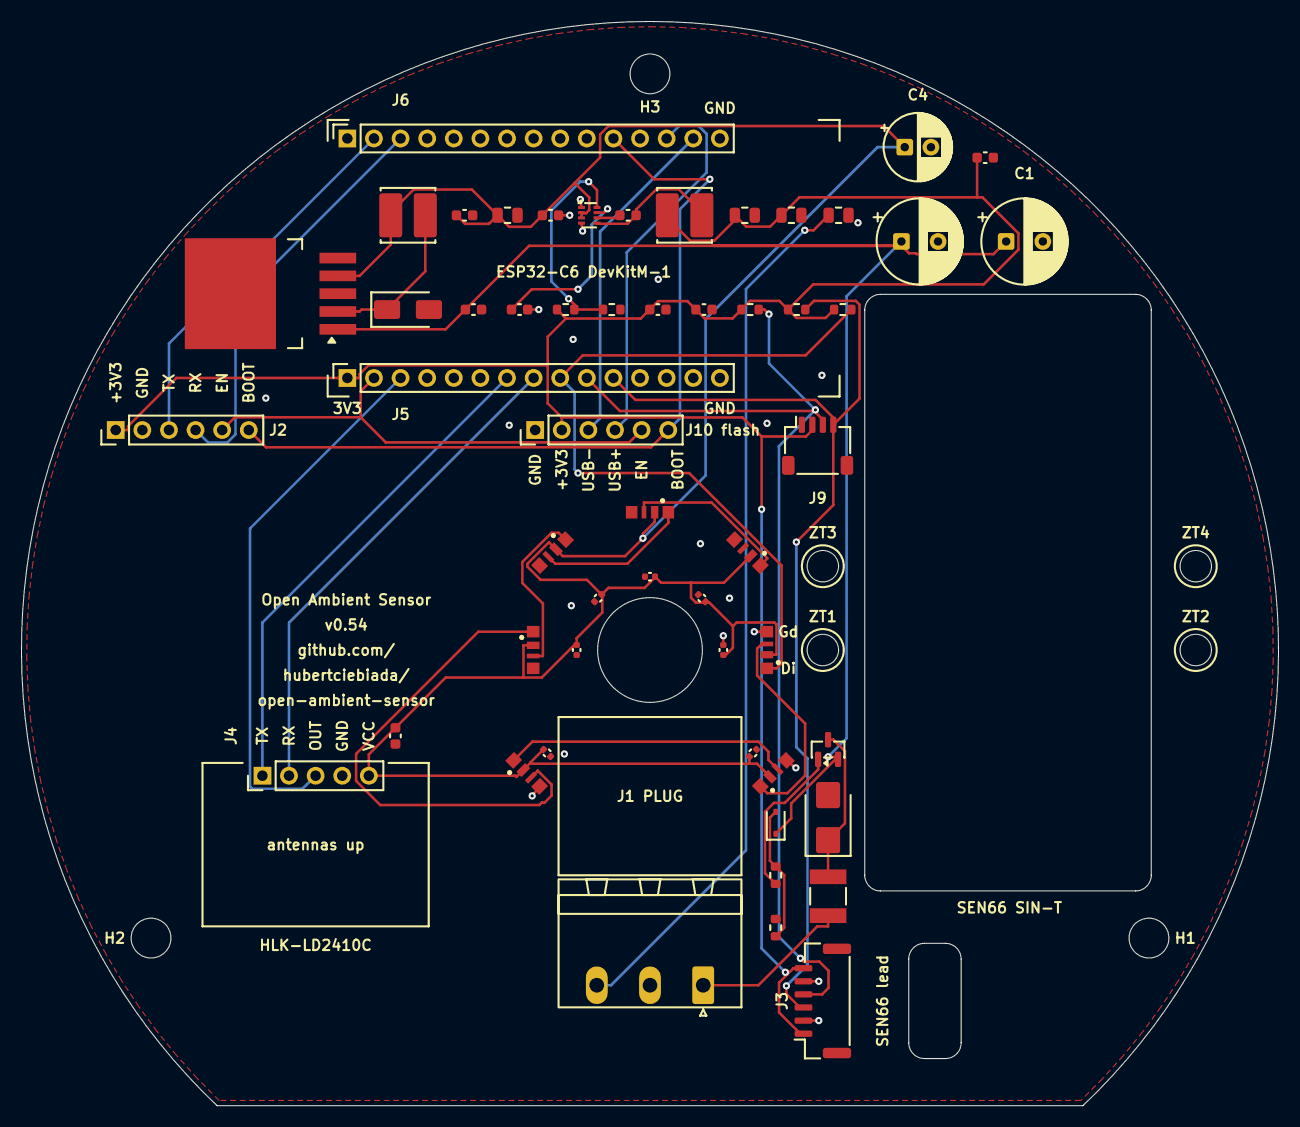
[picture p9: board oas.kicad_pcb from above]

Board: 2 copper layers, 120.0 x 103.5 mm, 64 parts (0 on the bottom side), 32 nets.

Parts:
C1, C3: 100uF/50V; CP_Radial_D8.0mm_P3.50mm
C2: 10nF Y2; C_0805_2012Metric
C4: 220uF/10V; CP_Radial_D6.3mm_P2.50mm
C5, C9: 10uF; C_0805_2012Metric
C6: 22uF; C_0805_2012Metric
C7, C10, C11, C13, C14, C15, C16, C17: 100nF; C_0603_1608Metric
C8: 47nF; C_0603_1608Metric
C20, C21, C23, C24, C25, C26, C27: 100nF; C_0402_1005Metric
D1: SMBJ24A; D_SMB
D2: SS14; D_SMA
D3: 10V Zener 200mW; D_SOD-323
D11, D12, D14, D15, D16, D17, D18: SK6812-SIDE
F1: 1812L075/33DR; Fuse_1812L_4532Metric
H1, H2, H3: MountingHole_3.8mm_M3_NPTH; MountingHole_3.8mm_M3
J1: Phoenix_MSTBA_2,5/3-G-5,08 (24V input); PhoenixContact_MSTBA_2,5_3-G-5,08_1x03_P5.08mm_Horizontal
J2: UART/Boot Recovery (DNP); PinHeader_1x06_P2.54mm_Vertical
J3: JST SM06B-GHS-TB (SEN66 connector); JST_GH_SM06B-GHS-TB_1x06-1MP_P1.25mm_Horizontal
J4: 1x5 P2.54mm header (HLK-LD2410C); PinHeader_1x05_P2.54mm_Vertical
J5: ESP32 row A (pins 1..15, antenna-side row); PinSocket_1x15_P2.54mm_Vertical
J6: ESP32 row B (pins 16..30, USB-side row); PinSocket_1x15_P2.54mm_Vertical
J9: JST SM04B-SRSS-TB (Qwiic / Stemma QT); JST_SH_SM04B-SRSS-TB_1x04-1MP_P1.00mm_Horizontal
J10: Native-USB recovery (DNP); PinHeader_1x06_P2.54mm_Vertical
L1: 33uH; L_Cenker_CKCS5040
L2: 2.2uH; L_Cenker_CKCS5040
LDR1: LD2410_Mechanical_Reference
MOD1: oas:ESP32-C6-DevKitM-1_Reference; ESP32-C6-DevKitM-1_Reference
Q1: AO3401A; SOT-23
R1: 100k 1%; R_0603_1608Metric
R2: 100k; R_0603_1608Metric
R3: 30.9k; R_0603_1608Metric
R4: 1k; R_0603_1608Metric
R5, R6: 4.7k; R_0603_1608Metric
R7: 10k; R_0603_1608Metric
SENS1: SEN66_Mechanical_Reference
U1: LM2596S-5.0; TO-263-5_LM2596
U2: TPS62933; SOT-583-8
ZT1, ZT2, ZT3, ZT4: ZipTieHole_3mm_NPTH

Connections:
+3V3: C6.1, C9.1, C10.1, C16.1, C17.1, J2.1, J3.1, J3.6, J5.1, J9.2, J10.2, L2.1, R2.1, R5.1, R6.1, R7.1
+5V: C4.1, C5.1, C11.1, C14.1, C15.1, C20.1, C21.1, C23.1, C24.1, C25.1, C26.1, C27.1, D11.2, D12.2, D14.2, D15.2, D16.2, D17.2, D18.2, J4.5, L1.1, U1.4, U2.2, U2.3
+24V: C1.1, C3.1, C13.1, D3.1, Q1.2, U1.1
/IO/BOOT: J2.6, J6.11, J10.6
/IO/EN: J2.5, J5.2, J10.5
/IO/I2C_SCL: J3.3, J5.11, J9.4, R6.2
/IO/I2C_SDA: J3.4, J5.10, J9.3, R5.2
/IO/USB_DM: J6.14, J10.3
/IO/USB_DP: J6.13, J10.4
/MCU/LD2410_OUT: J4.3, J5.3
/MCU/LD2410_UART_RX: J4.1, J5.7
/MCU/LD2410_UART_TX: J4.2, J5.8
/MCU/UART_RX: J2.4, J6.3
/MCU/UART_TX: J2.3, J6.2
/MCU/WS2812_DIN: D11.1, J5.9, R7.2
Earth_Protective: C2.1, J1.3
GND: C1.2, C2.2, C3.2, C4.2, C5.2, C6.2, C8.2, C9.2, C10.2, C11.2, C13.2, C14.2, C15.2, C16.2, C17.2, C20.2, C21.2, C23.2, C24.2, C25.2, C26.2, C27.2, D1.2, D2.2, D11.4, D12.4, D14.4, D15.4, D16.4, D17.4, D18.4, J1.2, J2.2, J3.2, J3.5, J4.4, J5.13, J5.15, J6.1, J6.12, J6.15, J9.1, J10.1, R1.2, R3.2, U1.3, U1.5, U2.1, U2.4
unnamed: D1.1, F1.2, Q1.3
unnamed: D2.1, L1.2, U1.2
unnamed: D3.2, R1.1, R4.2
unnamed: D11.3, D12.1
unnamed: D12.3, D14.1
unnamed: D14.3, D15.1
unnamed: D15.3, D16.1
unnamed: D16.3, D17.1
unnamed: D17.3, D18.1
unnamed: F1.1, J1.1
unnamed: Q1.1, R4.1
unnamed: C7.1, U2.6
unnamed: R2.2, R3.1, U2.8
unnamed: C8.1, U2.7
unnamed: C7.2, L2.2, U2.5

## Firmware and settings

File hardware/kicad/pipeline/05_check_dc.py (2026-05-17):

"""
OAS - DC voltage propagation check (pure Python).

Verifies the OAS power chain delivers correct regulated voltages when 24 V
is applied to J1. Catches resistor-value regressions like the v0.36
R3 10k -> 30.9k fix (pre-fix produced 4.34 V on +3V3 instead of 3.39 V,
which would have destroyed the ESP32 and SEN66 at first power-on) and
the v0.37 D3 18 V -> 10 V fix (pre-fix would have over-stressed the
AO3401A's +/-12 V Vgs rating).

Approach
--------
Reads the actual R-values + D3 Zener spec from `power.kicad_sch` (the
generated artifact - source-of-truth at simulation time), then runs
SIMPLIFIED ANALYTICAL MODELS of each active component to compute the
DC operating point at every named net. No SPICE engine needed -
just linear-network math with hardcoded IC datasheet behaviors.

Models used
-----------
  * D1 SMBJ24A (TVS):  Vbr ~ 26.7 V, Vcl ~ 38.9 V at 15 A peak.
                       Cathode tied to V_24V, anode to GND.
                       At nominal Vin=24V: reverse-biased, no DC effect.
  * Q1 AO3401A (P-FET): Vds_max=-30V, Vgs_max=+/-12V, Rds_on=45 mΩ @ Vgs=-10V.
                       Modeled as 45 mΩ series resistance when forward
                       conducting (Source at Vin, Drain at output side,
                       Gate pulled below Source via R4+R1 chain through D3).
  * D3 BZT52C10S (Zener): Vz=10 V at 5 mA test. Clamps Q1 Vgs at -Vz.
  * R1 100 k ohm:         Q1 gate pulldown to GND.
  * R4 1 k ohm:           Series gate-drive resistor (D3 clamp current limit).
  * F1 polyfuse:       Cold resistance ~0.1 Ohm (Littelfuse 2920L075/60MR).
  * U1 LM2596-5.0:     Ideal regulator. Vout = 5.0 V when 7 <= Vin <= 40 V.
                       Efficiency ~85% (modeled but doesn't affect Vout).
  * U2 TPS62933:       Ideal regulator. Vout = Vref × (1 + R2/R3),
                       Vref = 0.8 V. Valid when 3.8 <= Vin <= 30 V.
  * Loads:             Combined currents derived from CLAUDE.md per-component
                       budgets - ESP32 ~80 mA + SEN66 ~130 mA + NFC ~5 mA
                       + LD2410 ~80 mA + LED ring avg ~80 mA + misc.

Scenarios tested
----------------
  1. Nominal (Vin = +24 V): every regulated rail in spec window.
  2. Reverse polarity (Vin = -24 V): Q1 blocks, all downstream = 0 V.
  3. TVS clamp event (transient Vin spikes to +50 V): D1 clamps to 38.9 V,
     Q1 Vds stays within -30 V rating with margin.
  4. Brown-out (Vin = +6 V, below LM2596 minimum): rails collapse cleanly.

Exit code 0 if all checks pass, 1 on any assertion failure. Designed to
be run as a `regenerate.py` post-check OR standalone (`python tools/check_dc.py`).

Limitations
-----------
This is NOT a switching-converter simulator - soft-start ramp, output
ripple, transient response, and stability are NOT modeled. For those,
use TI WEBENCH or the KiCad built-in ngspice simulator with actual
PSpice models from TI. This tool is specifically designed to catch
DESIGN-VALUE regressions (resistor renumberings, Zener voltage drift,
component swap mistakes) that DRC and ERC cannot detect.
"""
from __future__ import annotations

import re
import sys
from dataclasses import dataclass
from pathlib import Path

HERE = Path(__file__).parent
KICAD_DIR = HERE.parent
POWER_SCH = KICAD_DIR / "power.kicad_sch"
MCU_SCH = KICAD_DIR / "mcu.kicad_sch"

# ---------------------------------------------------------------------------
# Component datasheet constants (sourced from datasheets, not LLM memory).
# Update only when the actual part is swapped in `lcsc-mapping.csv`.
# ---------------------------------------------------------------------------
TPS62933_VREF = 0.8         # TI TPS62933 datasheet Electrical Characteristics
TPS62933_VIN_MIN = 3.8      # TI TPS62933 minimum input voltage
TPS62933_VIN_MAX = 30.0
LM2596_VOUT_FIXED_5V = 5.0  # TI LM2596S-5.0 fixed-output variant
LM2596_VIN_MIN = 7.0        # TI LM2596 datasheet minimum operating Vin
LM2596_VIN_MAX = 40.0
SMBJ24A_VBR = 26.7          # Brightking SMBJ24A breakdown voltage
SMBJ24A_VCL = 38.9          # Clamp voltage at 15.4 A peak (600 W)
AO3401A_VDS_MAX_ABS = 30.0  # AOS AO3401A absolute max Vds (-30 V)
AO3401A_VGS_MAX_ABS = 12.0  # AOS AO3401A absolute max Vgs (+/-12 V)
AO3401A_RDS_ON = 0.045      # AOS AO3401A datasheet Rds(on) @ Vgs=-10V (Ω)
F1_COLD_R = 0.1             # Littelfuse 2920L075 cold trace resistance (Ω)

# OAS rail expected windows (datasheet-driven specs).
RAIL_5V_WINDOW = (4.85, 5.15)     # LM2596 +/-3% line+load
RAIL_3V3_WINDOW = (3.15, 3.60)    # SEN66 absolute spec window per datasheet section3
V24_PROT_WINDOW = (23.5, 24.05)   # After Q1 (45 mΩ * ~0.5A = 22.5 mV drop) + F1

# CLAUDE.md per-component current budgets (typical operating, not peak).
LOAD_5V_TYPICAL_A = 0.16    # LED ring avg 80 mA + LD2410 80 mA
LOAD_3V3_TYPICAL_A = 0.22   # ESP32 80 mA + SEN66 130 mA + NFC 5 mA + misc
TOTAL_INPUT_TYPICAL_A = 0.5  # rough total after buck efficiency losses


@dataclass
class CheckResult:
    """One named PASS/FAIL row, plus the actual value the test computed."""
    name: str
    value: str
    spec: str
    passed: bool

    def __str__(self) -> str:
        mark = "PASS" if self.passed else "FAIL"
        return f"  [{mark}] {self.name:35s} {self.value:30s} (spec: {self.spec})"


def parse_resistor_value(value_string: str) -> float | None:
    """Parse a KiCad value string like '100k', '30.9k 1%', '4.7k', '1k' into ohms.
    Returns None if the string can't be parsed."""
    # Pattern: <number><optional k/M/m suffix>[ optional tolerance]
    m = re.match(r"^\s*([\d.]+)\s*([kMm])?", value_string.strip())
    if not m:
        return None
    base = float(m.group(1))
    suffix = m.group(2) or ""
    multipliers = {"": 1.0, "k": 1e3, "M": 1e6, "m": 1e-3}
    return base * multipliers.get(suffix, 1.0)


def parse_zener_voltage(value_string: str) -> float | None:
    """Parse 'NV Zener ...' into the Zener voltage. Returns None if not matched.

    Handles formats like '10V Zener 200mW', '18V Zener 500mW', 'BZT52C10S'."""
    m = re.match(r"^\s*(\d+(?:\.\d+)?)\s*V\s+Zener", value_string)
    if m:
        return float(m.group(1))
    # BZT52CnnS family: nn = Zener voltage (no decimal).
    m = re.match(r"^\s*BZT52C(\d+)S?", value_string)
    if m:
        return float(m.group(1))
    return None


def read_schematic_property(sch_text: str, reference: str, prop: str) -> str | None:
    """Find the value of a named property on the first symbol whose Reference
    matches `reference`. Uses the same depth-counting parse as
    `generate.py:_apply_schematic_footprints` to handle nested blocks correctly."""
    i = 0
    n = len(sch_text)
    while True:
        idx = sch_text.find("(symbol", i)
        if idx == -1:
            return None
        depth = 0
        j = idx
        while j < n:
            ch = sch_text[j]
            if ch == "(":
                depth += 1
            elif ch == ")":
                depth -= 1
                if depth == 0:
                    j += 1
                    break
            j += 1
        block = sch_text[idx:j]
        m_ref = re.search(r'\(property "Reference" "([^"]+)"', block)
        if m_ref and m_ref.group(1) == reference:
            m_prop = re.search(
                r'\(property "' + re.escape(prop) + r'" "([^"]*)"',
                block,
            )
            return m_prop.group(1) if m_prop else None
        i = j


def read_design_values() -> dict[str, float]:
    """Parse `power.kicad_sch` + `mcu.kicad_sch` to extract every value
    that influences the DC operating point. Returns a dict of named
    quantities (ohms for resistors, volts for the Zener).

    Aborts with a clear error message if any expected reference is
    missing from the schematic - this catches the case where a
    component is accidentally removed before the simulation can warn
    that the design no longer matches the model.
    """
    power_text = POWER_SCH.read_text(encoding="utf-8")
    mcu_text = MCU_SCH.read_text(encoding="utf-8")

    def _r(text: str, ref: str) -> float:
        v = read_schematic_property(text, ref, "Value")
        if v is None:
            sys.exit(f"ERROR: {ref} missing from schematic - cannot simulate.")
        r = parse_resistor_value(v)
        if r is None:
            sys.exit(f"ERROR: {ref} value {v!r} not parseable as a resistance.")
        return r

    def _zener(text: str, ref: str) -> float:
        v = read_schematic_property(text, ref, "Value")
        if v is None:
            sys.exit(f"ERROR: {ref} missing from schematic - cannot simulate.")
        z = parse_zener_voltage(v)
        if z is None:
            sys.exit(f"ERROR: {ref} value {v!r} not parseable as a Zener voltage.")
        return z

    return {
        "R1": _r(power_text, "R1"),    # Q1 gate pulldown
        "R2": _r(power_text, "R2"),    # TPS62933 FB top
        "R3": _r(power_text, "R3"),    # TPS62933 FB bottom
        "R4": _r(power_text, "R4"),    # Q1 gate series resistor
        "R5": _r(mcu_text, "R5"),      # I2C pull-up
        "R6": _r(mcu_text, "R6"),      # I2C pull-up
        "R7": _r(mcu_text, "R7"),      # GPIO 8 bootstrap pull-up
        "D3_Vz": _zener(power_text, "D3"),
    }


# ---------------------------------------------------------------------------
# DC operating-point computation
# ---------------------------------------------------------------------------
def simulate_dc(vin: float, design: dict[str, float]) -> dict[str, float]:
    """Compute steady-state voltages at every named net of the OAS power chain
    for the given input voltage. Returns a dict of net -> volts. Negative
    voltages (e.g. for reverse-polarity input) propagate through the model
    correctly: Q1 blocks when Vgs is positive (P-FET off), so all downstream
    rails collapse to 0 V."""
    v = {}
    v["V_24V_RAW"] = vin

    # D1 SMBJ24A clamp: if Vin exceeds Vcl (38.9 V), clamp at Vcl.
    if vin > SMBJ24A_VCL:
        v["V_24V_RAW"] = SMBJ24A_VCL
    elif vin < -1.0:
        # SMBJ24A is unidirectional. With anode->GND and cathode->V_24V,
        # reverse polarity (Vin < 0) forward-biases the diode through
        # its anode-to-cathode path (Vf ~ 0.7 V) - D1 clamps the raw
        # rail at roughly -0.7 V regardless of how negative Vin is.
        v["V_24V_RAW"] = -0.7

    # Q1 AO3401A P-FET behavior. Source connects to V_24V_RAW, Gate
    # pulled toward GND via R1 (100 k ohm) and clamped via D3 Zener
    # through R4 (1 k ohm).
    v_source = v["V_24V_RAW"]
    # Compute the un-clamped Vgs the gate would settle at without D3.
    # With Q1 OFF, no gate current -> R1 pulls gate fully to 0 V ->
    # Vgs = V_gate - V_source = 0 - V_source = -V_source.
    vgs_open = 0.0 - v_source
    # D3 (Zener Vz=10) limits Vgs to no more negative than -Vz when forward
    # current flows (S -> D3 -> R4/R1 junction -> GND).
    if vgs_open < -design["D3_Vz"]:
        vgs = -design["D3_Vz"]
    else:
        vgs = vgs_open

    # Threshold check: AO3401A turns ON only when Vgs is more negative
    # than about -1 V (datasheet Vth_max). When Vsource < 0 (reverse
    # polarity), Vgs is POSITIVE so Q1 stays OFF and isolates downstream.
    q1_on = vgs <= -1.0 and v_source > 0.0

    if q1_on:
        # Q1 conducts with Rds_on series resistance. Drop across Q1 at
        # typical current is negligible (~22 mV at 0.5 A) for DC sanity.
        v_drop_q1 = TOTAL_INPUT_TYPICAL_A * AO3401A_RDS_ON
        v_after_q1 = v_source - v_drop_q1
        # F1 polyfuse adds another ~50 mV at typical current.
        v_drop_f1 = TOTAL_INPUT_TYPICAL_A * F1_COLD_R
        v["V_24V_PROT"] = v_after_q1 - v_drop_f1
    else:
        v["V_24V_PROT"] = 0.0

    # LM2596-5.0 buck (24 V -> 5 V). Ideal regulator within the
    # specified Vin window; otherwise output collapses.
    vin_lm2596 = v["V_24V_PROT"]
    if LM2596_VIN_MIN <= vin_lm2596 <= LM2596_VIN_MAX:
        v["+5V"] = LM2596_VOUT_FIXED_5V
    else:
        v["+5V"] = 0.0

    # TPS62933 buck (5 V -> 3.3 V) with R2/R3 feedback divider.
    vin_tps = v["+5V"]
    if TPS62933_VIN_MIN <= vin_tps <= TPS62933_VIN_MAX:
        v["+3V3"] = TPS62933_VREF * (1.0 + design["R2"] / design["R3"])
    else:
        v["+3V3"] = 0.0

    # Computed stress quantities (for safety-margin checks).
    v["Q1_Vgs"] = vgs
    v["Q1_Vds"] = v_source - v["V_24V_PROT"] if q1_on else v_source - 0.0
    # v0.40 post-order MATH FIX: D3 Zener dissipation. With Q1's gate at
    # DC high-impedance (Igss <= 100 nA), the gate-bias loop is
    # V_source -> D3 -> R1 (100 kohm gate pulldown) -> GND. R4 (1 kohm
    # gate series) carries NO steady-state current because R4 sits
    # between the R1/D3 junction and Q1.gate, and gate current is zero.
    # The pre-v0.40 expression used `design["R4"]` (1k) here which gave
    # 140 mW — 100x overstated. Correct expression uses design["R1"]
    # (100k) for I_z = (V_source - Vz) / R1 = 0.14 mA, so P_D3 = 1.4 mW
    # steady state. (R4 is documented in lcsc-mapping.csv row 11 + power
    # schematic; verified against power.kicad_sch R1 placement.)
    v["D3_P_diss"] = (
        ((v_source - design["D3_Vz"]) / design["R1"]) * design["D3_Vz"]
        if vgs <= -design["D3_Vz"] else 0.0
    )

    return v


def check_in_window(name: str, actual: float, lo: float, hi: float,
                     unit: str = "V") -> CheckResult:
    return CheckResult(
        name=name,
        value=f"{actual:.3f} {unit}",
        spec=f"[{lo:.2f}, {hi:.2f}] {unit}",
        passed=lo <= actual <= hi,
    )


def check_below(name: str, actual: float, limit: float, unit: str = "V") -> CheckResult:
    return CheckResult(
        name=name,
        value=f"{actual:.3f} {unit}",
        spec=f"<= {limit:.2f} {unit}",
        passed=actual <= limit,
    )


def main() -> None:
    print("OAS DC voltage propagation check")
    print("=" * 60)
    print()
    print("Reading design values from schematic...")
    design = read_design_values()
    print(f"  R1 = {design['R1']/1e3:.1f} k ohm (Q1 gate pulldown)")
    print(f"  R2 = {design['R2']/1e3:.1f} k ohm (TPS62933 FB top)")
    print(f"  R3 = {design['R3']/1e3:.1f} k ohm (TPS62933 FB bottom)")
    print(f"  R4 = {design['R4']/1e3:.1f} k ohm (Q1 gate series)")
    print(f"  R5 = {design['R5']/1e3:.1f} k ohm (I2C SDA pull-up)")
    print(f"  R6 = {design['R6']/1e3:.1f} k ohm (I2C SCL pull-up)")
    print(f"  R7 = {design['R7']/1e3:.1f} k ohm (GPIO 8 bootstrap pull-up)")
    print(f"  D3 = {design['D3_Vz']:.1f} V Zener (Q1 Vgs clamp)")
    print()

    all_results: list[CheckResult] = []

    # ---------- Scenario 1: Nominal +24 V ----------
    print("Scenario 1: Nominal Vin = +24.0 V")
    v = simulate_dc(+24.0, design)
    for name, val in v.items():
        if not name.startswith(("Q1_", "D3_")):
            print(f"  V({name}) = {val:.3f} V")
    print()
    s1 = [
        check_in_window("V(V_24V_PROT) - post-Q1+F1",
                         v["V_24V_PROT"], *V24_PROT_WINDOW),
        check_in_window("V(+5V) - LM2596 output",
                         v["+5V"], *RAIL_5V_WINDOW),
        check_in_window("V(+3V3) - TPS62933 output",
                         v["+3V3"], *RAIL_3V3_WINDOW),
        check_below("|Q1.Vgs| - AO3401A clamp",
                     abs(v["Q1_Vgs"]), AO3401A_VGS_MAX_ABS, "V"),
        check_below("D3.P_diss - BZT52C10S",
                     v["D3_P_diss"] * 1000, 200.0, "mW"),
    ]
    all_results.extend(s1)
    for r in s1:
        print(r)
    print()

    # ---------- Scenario 2: Reverse polarity -24 V ----------
    print("Scenario 2: Reverse polarity Vin = -24.0 V (D1 forward bias clamps to -0.7V)")
    v = simulate_dc(-24.0, design)
    for name, val in v.items():
        if not name.startswith(("Q1_", "D3_")):
            print(f"  V({name}) = {val:.3f} V")
    print()
    s2 = [
        check_in_window("V(+5V) - should be 0 V (Q1 off)",
                         v["+5V"], -0.01, 0.01),
        check_in_window("V(+3V3) - should be 0 V",
                         v["+3V3"], -0.01, 0.01),
    ]
    all_results.extend(s2)
    for r in s2:
        print(r)
    print()

    # ---------- Scenario 3: TVS clamp event +50 V transient ----------
    print("Scenario 3: TVS clamp event Vin = +50.0 V transient")
    v = simulate_dc(+50.0, design)
    for name, val in v.items():
        if not name.startswith(("Q1_", "D3_")):
            print(f"  V({name}) = {val:.3f} V")
    print()
    s3 = [
        check_below("V(V_24V_RAW) - D1 clamps to SMBJ24A Vcl",
                     v["V_24V_RAW"], SMBJ24A_VCL + 0.01),
        check_below("|Q1.Vds| - AO3401A absolute max",
                     abs(v["Q1_Vds"]), AO3401A_VDS_MAX_ABS,
                     "V (tight margin)"),
        check_below("|Q1.Vgs| - AO3401A absolute max",
                     abs(v["Q1_Vgs"]), AO3401A_VGS_MAX_ABS, "V"),
    ]
    all_results.extend(s3)
    for r in s3:
        print(r)
    print()

    # ---------- Scenario 4: Brown-out Vin = +6 V ----------
    print("Scenario 4: Brown-out Vin = +6.0 V (below LM2596 Vin_min = 7 V)")
    v = simulate_dc(+6.0, design)
    for name, val in v.items():
        if not name.startswith(("Q1_", "D3_")):
            print(f"  V({name}) = {val:.3f} V")
    print()
    s4 = [
        check_in_window("V(+5V) - should collapse cleanly",
                         v["+5V"], -0.01, 0.01),
        check_in_window("V(+3V3) - should collapse cleanly",
                         v["+3V3"], -0.01, 0.01),
    ]
    all_results.extend(s4)
    for r in s4:
        print(r)
    print()

    # ---------- Summary ----------
    total = len(all_results)
    failed = [r for r in all_results if not r.passed]
    print("=" * 60)
    if failed:
        print(f"FAIL: {len(failed)} of {total} checks failed.")
        for r in failed:
            print(f"  {r}")
        sys.exit(1)
    print(f"PASS: all {total} DC voltage checks passed.")


if __name__ == "__main__":
    main()

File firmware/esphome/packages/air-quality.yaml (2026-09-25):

# =============================================================================
# OAS — air quality package
# =============================================================================
#
# Sensirion SEN66 (combo: PM 1/2.5/4/10, CO2, VOC index, NOx index, T, RH) over
# I2C from a PCB-mounted JST-GH socket (J3). SEN66 is the headline sensor and
# Pillar #1 (measurement quality) anchor — see CLAUDE.md v0.6 / v0.15.8 / v0.22
# entries for the architectural decisions behind this stack.
#
# Wiring (per CLAUDE.md "ESP32-C6-DevKitM-1-N4 pinout (v0.4 final)" table):
#   - I2C SDA = GPIO 6
#   - I2C SCL = GPIO 7
#   - bus frequency = 100 kHz (Sensirion standard mode — SEN66 datasheet §3.1
#     hard limit; the realized OAS bus length is ~220 mm including the 80 mm
#     JST-GH cable to the SEN66 module, which is marginal for 400 kHz fast
#     mode; do NOT bump frequency without a signal-integrity measurement)
#   - SEN66 address = 0x6B (7-bit, fixed)
#
# This package also declares the primary I2C bus (id: bus_a) since the SEN66
# is the heaviest user. Any future Qwiic expansion package should
# reference `bus_a` rather than declaring its own.
#
# Datasheet refs (see EXTERNAL_MODULES['SEN66-SIN-T'] in hardware/kicad/boardgen/_project.py):
#   - Sensirion SEN6x datasheet v0.92, Dec 2025
#   - Sensirion SEN6x mechanical / assembly guidelines v0.92, Jan 2026
#   - Sensirion SEN6x temperature-compensation app note v1.1, Jan 2026
# =============================================================================

# ---------------------------------------------------------------------------
# STAR-Engine design-in constants (Sensirion SEN6x tcomp app note v1.1, 01/2026)
# ---------------------------------------------------------------------------
# What the SEN66 needs in order to report ROOM temperature from inside the OAS
# enclosure. Values that differ per unit (offsets, time constants) are `number:`
# entities further down (NVS-persisted, defaults = the reference unit). Values
# that are a property of the DESIGN live here as substitutions, so a device
# file can still override them without touching the package.
substitutions:
  # Normalised offset slope, dimensionless: how much the self-heating
  # over-temperature changes per kelvin of module temperature (AN §1.4).
  # 0 = the "basic" recipe (AN §2.2): one temperature level, constant offset.
  #
  # TODO (winter, AN §2.3.2): the slope needs the steady-state offset at a
  # SECOND room temperature, ideally ~10 K away from the level the offset was
  # derived at (summer, room ~23 °C). No experiment needed: with the room
  # steady near 19 °C (no AC, no sun on the enclosure, ≥ 6 h, references next
  # to the unit) read the offset the same way as in summer (T_ref - T_module
  # averaged over the last hour). If it differs from the summer value by more
  # than the reference uncertainty (~0.2 K):
  #   slope = (offset_high - offset_low) / (T_module_high - T_module_low)
  # and set it here. The engine then applies offset(T) = C_0C + slope * T_module;
  # the send script converts the room-level "Temperature Offset" number into
  # C_0C with `sen66_star_slope_ref_c`, so the number keeps its room meaning.
  # Worked example: summer -3.4 at T_module 26.3, winter -3.6 at T_module 22.6
  #   -> slope = 0.2 / 3.7 = 0.054, C_0C = -3.6 - 22.6 * 0.054 = -4.82
  #   -> wire values slope 540 (×10000), offset -964 (×200).
  # The slope is applied to slot 0 only (the base self-heating); slot 1 keeps 0.
  sen66_star_slope: "0"
  # Module temperature (°C, as reported by the SEN66) at which the slot-0
  # "Temperature Offset" number was determined. Only used when the slope is
  # non-zero. Reference unit, summer: room 22.9 °C + 3.4 K over-temperature.
  sen66_star_slope_ref_c: "26.3"
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

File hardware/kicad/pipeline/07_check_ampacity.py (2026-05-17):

"""
OAS - Trace ampacity check (IPC-2221 external trace formula).

For each power rail with a known peak-current budget, finds the narrowest
track segment carrying that net on the PCB and verifies its width
delivers enough ampacity per IPC-2221 chart "Maximum current vs
cross-section for external conductors" (1 oz copper, 10 C rise above
ambient).

Catches the class of bug where a route through a tight pocket gets
pinched down (e.g. autoroute or hand-edit drops width from 0.5 mm to
0.25 mm to fit between two pads), unintentionally creating a current-
limited segment that becomes a fuse under peak load.

IPC-2221 formula
----------------
   I_max = k * dT^0.44 * A^0.725
where:
   I_max   : maximum continuous current (amps)
   k       : 0.048 for external conductors, 0.024 for internal
   dT      : permitted temperature rise above ambient (degrees C)
   A       : cross-sectional area (mil^2) = width_mil * thickness_mil
   thickness_mil = 1.378 for 1 oz copper

For OAS this is a 2-layer board, so both F.Cu and B.Cu are external
layers and use k=0.048. The check uses dT = 10 C (conservative).

Net CONTINUOUS current budgets
------------------------------
IPC-2221 is a STEADY-STATE thermal model - the trace heats up to
equilibrium under sustained current. Transient peaks (e.g. LED ring at
full white during boot self-test for 100 ms) don't drive trace
temperature past the dT_C ambient rise. Therefore the budgets below
reflect realistic CONTINUOUS load, not absolute peak.

   +24V   : Total system input. P_total ~ 5 W / 24 V ~ 210 mA continuous.
            Budget 0.30 A (40 % margin over computed).
   +5V    : LD2410 80 mA + TPS62933 input ~340 mA (powering +3V3 loads
            at 435 mA via ~85 % buck) + LED ring sustained avg ~200 mA
            (worst case = solid red AQI alert for hours) -> ~620 mA
            continuous. Budget 0.70 A.
   +3V3   : ESP32 80 mA + SEN66 typ 200 mA (peak 350 mA is transient
            during fan startup, not steady state) + NFC 5 mA -> ~290 mA
            continuous. Budget 0.45 A.
   GND    : carried by the copper pour (~Ø120 mm minus cutouts).
            Skipped - pour ampacity is huge vs trace ampacity.
   Signals: low-current (mA range) - skipped here, signal integrity
            handled elsewhere (rise-time check, see CLAUDE.md I2C).

Exit code 0 if every monitored net's minimum-width segment delivers at
least the budget current. Exit 1 on any FAIL.
"""
from __future__ import annotations

import re
import sys
from dataclasses import dataclass
from pathlib import Path

HERE = Path(__file__).parent
KICAD_DIR = HERE.parent
PCB_PATH = KICAD_DIR / "oas.kicad_pcb"

# IPC-2221 formula constants.
K_EXTERNAL = 0.048
K_INTERNAL = 0.024
DT_C = 10.0  # temperature rise above ambient (deg C). Conservative.
COPPER_THICKNESS_MIL_1OZ = 1.378  # IPC-2221 spec.

# Net continuous current budgets (Amps). See module docstring for derivation.
# Note: the OAS schematic uses a single "+24V" power flag spanning J1 input,
# post-Q1, and post-F1 - so the whole 24 V chain is one net in the PCB.
NET_BUDGETS = {
    "+24V": 0.30,
    "+5V":  0.70,
    "+3V3": 0.45,
}

# Minimum acceptable safety margin (1.0 = exactly at IPC limit).
# OAS sets 1.2 = 20% headroom over the budgeted peak.
SAFETY_FACTOR = 1.2


@dataclass
class Segment:
    net_code: int
    width: float  # mm
    layer: str
    start: tuple[float, float]
    end: tuple[float, float]

    def length_mm(self) -> float:
        dx = self.end[0] - self.start[0]
        dy = self.end[1] - self.start[1]
        return (dx * dx + dy * dy) ** 0.5


@dataclass
class CheckResult:
    name: str
    value: str
    spec: str
    passed: bool

    def __str__(self) -> str:
        mark = "PASS" if self.passed else "FAIL"
        return f"  [{mark}] {self.name:30s} {self.value:38s} (spec: {self.spec})"


def ipc2221_max_current_a(width_mm: float, layer: str) -> float:
    """Compute IPC-2221 max continuous current for a single-segment trace."""
    width_mil = width_mm / 0.0254
    area_mil_sq = width_mil * COPPER_THICKNESS_MIL_1OZ
    is_external = layer.startswith("F.") or layer.startswith("B.")
    k = K_EXTERNAL if is_external else K_INTERNAL
    return k * (DT_C ** 0.44) * (area_mil_sq ** 0.725)


def min_width_for_current_mm(current_a: float, layer: str = "F.Cu") -> float:
    """Inverse of ipc2221_max_current_a - returns the required trace width
    (mm) to safely carry the given current."""
    is_external = layer.startswith("F.") or layer.startswith("B.")
    k = K_EXTERNAL if is_external else K_INTERNAL
    # I = k * dT^0.44 * (w_mil * t_mil)^0.725
    # -> w_mil = ((I / (k * dT^0.44)) ** (1/0.725)) / t_mil
    area_mil_sq = (current_a / (k * (DT_C ** 0.44))) ** (1.0 / 0.725)
    width_mil = area_mil_sq / COPPER_THICKNESS_MIL_1OZ
    return width_mil * 0.0254


def parse_nets(pcb_text: str) -> dict[int, str]:
    """Parse all (net N "name") declarations at the top of the PCB file."""
    return {
        int(code): name
        for code, name in re.findall(r'\(net\s+(\d+)\s+"([^"]*)"\)', pcb_text)
    }


def parse_segments(pcb_text: str) -> list[Segment]:
    """Parse every (segment ...) block. Uses depth-counting to handle
    nested parens robustly."""
    segments: list[Segment] = []
    i = 0
    n = len(pcb_text)
    while True:
        idx = pcb_text.find("(segment", i)
        if idx == -1:
            break
        # Must be at start of line (segment is always top-level in a
        # (kicad_pcb ...) doc) - but allow leading whitespace.
        # Walk to balanced close paren.
        depth = 0
        j = idx
        while j < n:
            ch = pcb_text[j]
            if ch == "(":
                depth += 1
            elif ch == ")":
                depth -= 1
                if depth == 0:
                    j += 1
                    break
            j += 1
        block = pcb_text[idx:j]

        m_start = re.search(r'\(start\s+([\d.-]+)\s+([\d.-]+)\)', block)
        m_end = re.search(r'\(end\s+([\d.-]+)\s+([\d.-]+)\)', block)
        m_width = re.search(r'\(width\s+([\d.]+)\)', block)
        m_layer = re.search(r'\(layer\s+"([^"]+)"\)', block)
        m_net = re.search(r'\(net\s+(\d+)\)', block)
        if m_start and m_end and m_width and m_layer and m_net:
            segments.append(Segment(
                net_code=int(m_net.group(1)),
                width=float(m_width.group(1)),
                layer=m_layer.group(1),
                start=(float(m_start.group(1)), float(m_start.group(2))),
                end=(float(m_end.group(1)), float(m_end.group(2))),
            ))
        i = j
    return segments
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

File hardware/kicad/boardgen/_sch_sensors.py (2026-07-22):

"""boardgen/_sch_sensors.py - sensors.kicad_sch generator."""
from __future__ import annotations

import textwrap

from boardgen._common import U, fmt, sheet_context, SCH_VERSION, GEN_VERSION, SHEET_FILE_UUIDS, ROOT_SHEET_UUID, SUBSHEET_DISPLAY_NAMES
from boardgen._project import fx, fy, PROJECT_SHORTNAME, LED_RING_COUNT, LED_RING_SKIP_INDICES
from boardgen._lib_symbols import SENSORS_LIB_SYMBOLS
from boardgen._sch_helpers import (
    _sch_wire, _sch_junction, _sch_power_flag,
    _sch_capacitor, _sch_hierarchical_label, _sch_no_connect,
    _sch_local_label, _sch_sk6812_side,
    _sch_conn_01x06, _sch_conn_01x04,
    _sch_conn_01x05,
)


# -----------------------------------------------------------------------------
# gen_sensors_sch
# -----------------------------------------------------------------------------
def gen_sensors_sch() -> str:
    """Sensors sub-sheet — chunks #5a + #5b.

    Chunk #5a — SEN66 connection (J3 + C10).
    Chunk #5b — HLK-LD2410C mmWave radar (J4 + C11). The module mounts as
                a soldered daughterboard on a 5-pin 2.54 mm through-hole
                header at J4; mechanical retention is the solder joint.
                Antenna faces the AK-N-94 perforated cover (away from
                the OAS PCB) per the HiLink §5.5 antenna-clearance rule
                and the universal community pattern (Apollo MSR-2,
                jonnybergdahl, p2baron). PCB footprint chosen in
                chunk #7.
    Chunk #5c — REMOVED (issue #7): the MIKROE-2462 NFC Tag 2 Click
                daughterboard (J7 + J8 + C12) left the design together
                with the NFC feature.

    SEN66 MODULE-side pinout (Sensirion SEN6x datasheet v0.92 Dec 2025,
    Table 16 on p. 15) — applies to the entire SEN6x family (SEN62,
    SEN63C, SEN65, SEN66, SEN68, SEN69C):

      Pin 1: VDD  — Supply voltage (3.15-3.6 V)
      Pin 2: GND  — Ground
      Pin 3: SDA  — Serial data input/output (I²C, open-drain)
      Pin 4: SCL  — Serial clock input         (I²C, open-drain)
      Pin 5: GND  — Ground or NC  (internally tied to pin 2)
      Pin 6: VDD  — Supply voltage or NC (internally tied to pin 1)

    J3 (the OAS board-side socket) is wired as the positional MIRROR of
    Table 16 (CLAUDE.md Lesson 21; GitHub issue #6; bench-confirmed
    2026-06-30):

      J3 pin 1: VDD    pin 2: GND    pin 3: SCL
      J3 pin 4: SDA    pin 5: GND    pin 6: VDD
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

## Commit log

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2026-05-11 KiCad 10 base project: board outline + mounting holes from AK-N-94 DXF
    Bootstrap the KiCad project with geometry derived from the SZOMK AK-N-94
    manufacturer DXF. The DXF itself is not committed (Rule 6 — third-party IP);
    only own work derived from it (KiCad files, geometry constants, dimension
    documentation).
    hardware/kicad/:
    - oas.kicad_pcb: PCB with Edge.Cuts outline (Ø120 mm D-shape: arc R=60 mm
    + flat chord 82.6 mm at the bottom edge) and 3× M3 mounting holes
    (Ø3.8 mm) on pitch circle Ø110 mm
    - oas.kicad_pro: project with JLCPCB-compatible design rules
    (0.15 mm trace/space, 0.3 mm hole, 0.3 mm edge clearance) and Default
    + Power net classes
    - oas.kicad_sch: empty schematic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
    [oas.kicad_pcb, oas.kicad_sch]
2026-05-11 Hide Reference/Value on mounting-hole footprint to pass DRC
    The Reference label on H3 (the top mounting hole, at Y=−55 mm) was
    positioned at footprint-local (0, −4.5), placing it at global Y=−59.5 mm
    — flush with the Ø120 mm board edge at Y=−60. kicad-cli DRC flagged this
    as a silk_edge_clearance violation (clearance 0.0 mm, rule 0.15 mm).
    Standard KiCad library mounting-hole footprints hide both Reference and
    Value (no purpose under a screw head). Adopting the same convention here:
    move both fields to (0, 0) and add (hide yes).
    Verified clean with KiCad 10.0.2:
    kicad-cli pcb drc → 0 violations
    kicad-cli pcb render → looks correct
    kicad-cli pcb export svg → parses cl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
    [oas.kicad_pcb, oas.kicad_sch]
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2026-05-11 Audit fixes: deterministic UUIDs, chord 82.6→82.65, HAL→HASL
    Audit (run by code-reviewer agent) flagged three items to fix before
    moving on to the schematic. All three addressed here.
    1. **Deterministic UUIDs in generate.py.**
    Previously `uuid.uuid4()` produced new random UUIDs on every run,
    so `python generate.py` always made a noisy diff even when nothing
    meaningful had changed. Now uses `uuid.uuid5(NS, "tag:counter")`
    namespaced under the project. Verified bit-identical output across
    two consecutive runs (md5 stable).
    2. **Flat chord 82.6 → 82.6545 mm.**
    The CAD DIMENSION in the DXF rounded to 82.5 for display, but the
    actual chord line measures 82.6545 mm. Di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
    [oas.kicad_pcb, oas.kicad_sch]
2026-05-11 Add 5 connector-cutout no-go zones (keepouts) + Dwgs.User markers
    User asked for no-go zones along the flat chord where the SZOMK AK-N-94
    enclosure has 5 cutouts in its case wall for connector pass-through.
    Goal: prevent accidentally routing tracks or placing components into the
    area where a connector body must sit, before we even know which
    connector goes into each slot.
    Geometry extracted from the manufacturer DXF — for each of the 5 cutouts,
    the exact rectangle in PCB-local coordinates (origin = centre of PCB
    outline; +Y toward the chord = visually bottom in pcbnew):
    | # | size mm | position vs. chord |
    |---|------------|------------------------------------|
    | C1| 12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
    [oas.kicad_pcb]
2026-05-11 PCB regeneration pipeline + committed render previews
    Codify the script-driven workflow that we established this session:
    the .kicad_pcb/.kicad_sch/.kicad_pro files are derived artefacts, the
    source-of-truth is the Python. To change anything geometric/structural,
    edit `generate.py` and run a single command.
    New: `hardware/kicad/regenerate.py` — master script.
    1. python generate.py (rebuild KiCad source files)
    2. kicad-cli pcb drc / sch erc (fail on errors and warnings)
    3. kicad-cli pcb export svg (2D top / cutouts / bottom previews)
    4. cairosvg svg → png (committable PNGs)
    5. kicad-cli pcb render (3D top, ~15 s)
    Runs end-to-end in ~30 s. Bit-identical re-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
    [regenerate.py]
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2026-05-11 kicad: reverse-polarity protection P-MOSFET (Q1) on +24V input
    Adds high-side P-MOSFET reverse-polarity protection between
    J1 pin 1 and the +24V rail. Q1 (AO3415A, SOT-23, Vds=-40V,
    Id=-4A, RDS(on)~70mOhm@-10V) conducts via body diode then
    enhances through inverted Vgs when polarity is correct;
    under reversed polarity the body diode and channel are both
    blocked.
    R1 (100k 0603) is the gate-GND pulldown that generates the
    negative Vgs needed to turn Q1 on. Vgs at nominal 24V is
    well inside the AO3415A +/-25V absolute maximum, so no Vgs
    clamp Zener is required.
    The +24V power-flag symbol and its PWR_FLAG sentinel move
    from J1 pin 1 to Q1 drain - i.e. the "+24V" net name now
    refers to the prot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
    [power.kicad_sch]
2026-05-11 kicad: PTC fuse F1 + schematic render pipeline + power layout rework
    Three bundled changes to the power-input section:
    1. regenerate.py now exports every hierarchical sheet to
    renders/sch-<name>.{svg,png} via kicad-cli sch export svg.
    Gives reviewers and future agents a visual feedback loop
    for schematic edits, mirroring what we already have for
    PCB renders.
    2. gen_power_sch() reworked: power flow is now left-to-right
    (J1 input on the left, protected +24V rail exiting to the
    right via Q1 and F1). Column spacing widened to ~15 mm
    between independent vertical wire columns. PWR_FLAG
    sentinels rotated 90 deg so their text labels sit beside
    the symbol rather than abov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
    [power.kicad_sch]
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2026-05-11 kicad: bulk cap C1 + Y-cap C2 (close power input section)
    Adds the final two components of the 24V input protection
    chain:
    C1 (100uF 50V electrolytic) sits across the protected +24V
    rail to GND, downstream of F1. Buffers transient load steps
    from the WS2812 LED, mmWave radar refreshes, MCU TX bursts,
    and absorbs ripple from the upstream supply. 50V rating
    gives margin over both the 24V nominal and the SMBJ24A's
    38.9V surge-clamping voltage.
    C2 (10nF Y2 ceramic) sits between circuit GND and the PE
    conductor (Earth_Protective net from J1 pin 3). Closes the
    conducted-EMI loop so high-frequency switching noise from
    the downstream bucks returns to chassis ground through this
    cap rather than esc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
    [power.kicad_sch]
2026-05-11 kicad: 24V to 5V buck converter (LM2596S-5.0, U1)
    First active block: asynchronous step-down buck producing a
    regulated 5V rail from the protected +24V input. Powers the
    LD2410 mmWave radar and the WS2812 status LED.
    Component selection rationale:
    - LM2596S-5.0 (40V Vin_max, fixed 5V output, 3A, 150kHz,
    TO-263 DPAK): the 40V rating is critical because D1
    (SMBJ24A) clamps surges at 38.9V - lower-rated bucks
    (TPS62933, MP2451, MP1584) would die under those events.
    Fixed-output variant eliminates the FB divider and one
    potential source of layout error.
    - L1: 33uH shielded inductor, 1A sat - sized per LM2596
    datasheet for 5V output at 150kHz with up to ~500mA load.
    - D2: SS14 Schott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
    [power.kicad_sch]
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2026-05-11 kicad: post-review fixes - Q1 (DMP4015SK3) + F1 (60V PTC)
    Addresses three findings from the schematic review run
    after ab0893f:
    BLOCKER fix: Q1 changed AO3415A -> DMP4015SK3. The original
    AO3415A spec was misread - actual Vds_max is -20V and
    Vgs_max is +/-8V (not -40V / +/-20V as previously
    documented). At 24V input the part would be destroyed on
    first power-up because Vgs = -24V exceeds the +/-8V
    absolute maximum by 3x. DMP4015SK3 from Diodes
    Incorporated provides Vds_max = -40V (margin over the
    38.9V SMBJ24A surge clamp), Vgs_max = +/-20V (tolerates
    the full 24V gate-source drive cleanly), Id_max = -5A,
    RDS(on) ~70mOhm at Vgs=-10V, SOT-23-3 drop-in. JLCPCB
    Extended Parts Library (acceptab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
    [power.kicad_sch]
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2026-05-11 kicad: chunk #1h - second-review fixes (Q1 Zener clamp, L1 uprate, SS cap, PMV65XP)
    Applies four fixes from the second schematic review.
    BLOCKER (Q1 Vgs overdrive): Adds D3 (18V Zener) + R4 (1k series)
    gate-source clamp to Q1. Without the clamp, Vgs at 24V supply
    sits at -24V - exceeds PMV65XP/DMP4015SK3's Vgs_max +/-20V
    absolute maximum by 20%, eventually destroying the gate oxide.
    The Zener clamps |Vgs| to <=18V; R4 limits clamp current to
    ~6mA. The R1 (100k) gate pulldown still provides the normal
    "turn FET on" default state.
    HIGH (L1 saturation margin): L1 spec changed from 33uH/1A sat
    to 33uH/2A sat. Cold-start of C4 (220uF output cap) can push
    peak inductor current above 1A in the fi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
    [power.kicad_sch]
2026-05-12 kicad: D3 value field - include power rating (18V Zener 500mW)
    Closes the MEDIUM finding from the third review: D3's BOM value
    field previously read just '18V Zener', omitting the 500mW power
    rating that is part of the requirement. Without the rating in the
    BOM-visible field, there was a risk at PCB-layout time of picking
    a Zener with the wrong package (SOD-323 vs SOD-123) or insufficient
    power-handling for the worst-case clamping event.
    The MMSZ4705 candidate (500mW, SOD-123, JLCPCB Basic) remains in
    the comment as the recommended specific part. The value field now
    encodes the full minimum requirement.
    Pure value-string change. No topology, no symbol, no netlist
    change. ERC unchanged at 0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
    [power.kicad_sch]
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2026-05-12 kicad: chunk #4 fix - J2 recovery header pinout (all 6 signals)
    Fixes a layout bug in commit 2e83a5b: J2 (SWD/UART recovery,
    DNP) had pin 1 left unconnected and the UART_RX wire passed
    2.54 mm below J2 pin 6 without actually tapping into the
    connector. A dangling junction at (194.31, 109.22) marked
    where UART_RX should have entered but didn't. Net effect:
    the recovery header was missing UART_RX, making it useless
    for actual recovery flashing.
    Refactored gen_mcu_sch() to map all 6 required recovery
    signals into J2:
    - Pin 1: +3V3 (programmer supplies power if needed)
    - Pin 2: GND
    - Pin 3: UART_TX (GPIO16)
    - Pin 4: UART_RX (GPIO17)
    - Pin 5: EN (reset)
    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
    [mcu.kicad_sch]
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2026-05-12 kicad: chunk #4 fix - v0.4 pinout + I2C pullups + DevKitM-1 symbol rebuild
    Replace the OAS:ESP32-C6_SuperMini custom symbol (modeled on a generic 2x8
    SIP, 16 pins) with OAS:ESP32-C6_DevKitM-1, built from the Espressif official
    user guide pin layout (2x15 SIP, 30 pins total, J1 left + J3 right). Symbol
    description carries MPN, EAN, datasheet URL, and chip-level notes (SiP flash,
    GPIO 10/11 not bonded, 22 GPIOs available).
    Apply the v0.4 signal-routing corrections:
    * LD2410_OUT: GPIO 10 (does not exist on SiP flash) -> GPIO 2 (safe input)
    * NFC_FD: GPIO 11 (does not exist on SiP flash) -> GPIO 3 (safe input)
    Add the I2C pullups flagged HIGH by the chunk #4 review:
    * R5: 4.7k 1% 0402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
    [mcu.kicad_sch]
2026-05-12 docs+kicad: v0.6 - SEN66 moves to PCB + I2C pullup 4.7k->10k
    Architectural reversal: SEN66 mounts directly on the PCB inside the
    enclosure (no longer on the cover via JST-GH cable). Air-side face
    points UP toward the AK-N-94 perforated cover; back face flat on PCB.
    Body sticks 21.5 mm above PCB. Lifts hard constraint #1 from 17 mm to
    >=22 mm in the SEN66 zone -- regional limit per CASE-VERIFICATION
    section 1 (likely peripheral-only DXF annotation).
    Mechanical retention: 4 zip-tie NPTH holes in PCB along the long
    edges of the SEN66 footprint, in two corridors that avoid the air
    openings (positions extracted from Sensirion STEP files):
    Pair 1: X ~25 mm (between inlets at X<=18.22 and outlet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
    [mcu.kicad_sch]
2026-05-12 kicad: chunk #5a - SEN66 reference footprint + 4 zip-tie NPTH + J3 socket
    Adds the SEN66 (Sensirion SEN66-SIN-T, MPN 3.001.030, EAN N/A) connection
    to the sensors sub-sheet and lays out the mechanical reference + retention
    on the PCB. Resolves 2 of 6 expected ERC pin_not_connected (I2C_SDA, SCL).
    Schematic (sensors.kicad_sch):
    J3 = JST GH 6-pin board socket (SM06B-GHS-TB compatible). Wiring per
    SEN6x datasheet Table 16: 1=VDD->+3V3, 2=GND, 3=SDA, 4=SCL,
    5=GND-redundant, 6=VDD-redundant (pins 5/6 internally tied to 1/2 in
    the SEN6x). Local 100 nF decoupling (C10) on the cable side of J3.
    Custom PCB footprints:
    oas:SEN66_Mechanical_Reference - 55.2 x 25.6 mm body outline on F.Fab +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
    [mcu.kicad_sch, oas.kicad_pcb, oas.kicad_sch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]
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2026-05-12 kicad: make U() deterministic by tag (drop counter, add sheet context)
    The prior U(tag) returned uuid5(NS, f"{tag}:{counter}") with a global
    per-run counter. Tags were nominally deterministic but every U() call
    incremented the counter, so adding or removing ONE call anywhere
    shifted every subsequent UUID. That was the cause of the wire-UUID
    churn observed in the previous commit's .sch diffs.
    Fix:
    - U(tag) now returns uuid5(NS, tag) directly. Tag uniqueness is the
    caller's responsibility; U() asserts no tag is reused within a run.
    - The 32 bare U() calls inside gen_mounting_hole_footprint() and the
    H1/H2/H3 mounting-hole instances in gen_pcb() are converted to
    explicit tags (mh-lib:*,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
    [mcu.kicad_sch, oas.kicad_pcb, oas.kicad_sch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]
2026-05-12 kicad: clear silkscreen DRC warnings (text size, edge clearance, C4 overlap)
    The C1..C5 AUX cutout silk labels triggered 9 DRC warnings on the
    prior PCB: 5 text_height (silk text 0.8 mm < 1.0 mm DRC minimum),
    3 silk_edge_clearance (cutout rectangles on C2/C3/C4 touching the
    chord because they were drawn at y=Y_CHORD exactly), and 1 silk_overlap
    (C4 AUX text overlapping the rect outline in the narrow 4 mm cutout).
    Fixes in gen_silk_labels():
    - Cutout silk rectangle is inset by SILK_EDGE_INSET = 0.3 mm on all
    sides. With the 0.12 mm silk stroke, this leaves 0.24 mm clear of
    Edge.Cuts -- comfortably above the 0.15 mm DRC minimum.
    - "C# AUX" text size bumped from 0.8 -> 1.0 mm (DRC minimum)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
    [oas.kicad_pcb]
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2026-05-12 kicad: v0.9 - J3 below SEN66, SEN66 pushed up+right near max
    Layout reshuffle so J3 sits directly under the SEN66 body shadow
    instead of east of it, with a 3 mm gap between SEN66 body bottom and
    J3 body north edge.
    Position changes:
    - SEN66 anchor: (17, 25) -> (23.5, 22)
    Body shadow: X 17..42.6, Y -30.2..25 -> X 23.5..49.1, Y -33.2..22
    Body right edge X=49.1 sits ~0.8 mm inside the PCB outline at the
    body top (Y=-33.2, outline x_max=49.98). Body bottom Y=22 clears
    the H1 mounting-hole courtyard (Y range 24.65..30.35) by 2.65 mm,
    so the body right edge is free to enter H1's X range without
    any courtyard collision.
    - Zip-tie holes ZT1..ZT4 follow the SEN66 anchor automatically v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
    [oas.kicad_pcb]
2026-05-12 docs+firmware: v0.10 - drop VEML7700 ambient light sensor
    VEML7700 was originally a "bolt-on" feature in the OAS spec, not core
    to the air-quality + presence mission. Planning chunk #5b/#5c sensor
    placement raised the geometric light-shielding problem: the DevKitM-1's
    onboard NeoPixel (status LED, breathing animation) and always-on power
    LED sit inside the same closed white-perforated AK-N-94 enclosure.
    Internal reflection off the cover ABS + direct line-of-sight on the
    PCB would bias VEML7700 lux readings, especially at low ambient.
    Mitigations evaluated:
    - Geometric shielding (opposite-quadrant placement + opaque shroud)
    - Internal 3D-printed baffle wall between MCU and VEML7700 zones
    - S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
    [generate.py]
2026-05-12 kicad: chunk #5b - LD2410 mmWave radar (J4 + C11) in sensors.kicad_sch
    Adds the HLK-LD2410B presence radar connection to the sensors sub-sheet.
    Resolves 4 of the 5 ERC issues that remained after chunk #5a:
    - 3 sensors-side hier labels (LD2410_OUT, UART_TX, UART_RX) now exist
    and are wired through to the MCU side
    - 3 root-sheet inter-sheet wires bind the matching sensors/mcu sheet
    pins so KiCad ERC sees the cross-sheet nets as electrically continuous
    Schematic content (sensors.kicad_sch):
    J4 — JST SM05B-GHS-TB 5-pin board socket, mates with HLK-LD2410B
    stock cable. Pinout (per HiLink LD2410B datasheet):
    Pin 1: VCC (+5V from U1)
    Pin 2: GND
    Pin 3: TX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
    [oas.kicad_sch, sensors.kicad_sch]
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2026-05-12 kicad: chunk #5b PCB - LD2410 mechanical reference + J4 through-hole
    Reserves the LD2410 daughterboard's projected shadow on the OAS PCB so
    subsequent placement work (chunk #5c NT3H2211, chunk #6 io.kicad_sch,
    chunk #7 PCB routing) knows where the radar lives and stays clear.
    Also lands J4 as the physical solder anchor that retains the LD2410.
    Placement (PCB-local, anchor at the body's lower-left corner):
    LD2410 body shadow : X = -45.72 .. -10.16, Y = -25.4 .. -10.16
    (35.56 x 15.24 mm; antenna patches at the -X
    end, connector edge at the +X end facing OAS
    centre for short signal traces to the MCU.)
    J4 pin row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
    [oas.kicad_pcb]
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2026-05-12 kicad: fix J4 pin row centering on LD2410 body axis (rotation 90 -> 270)
    Empirical KiCad-rotation analysis from the v0.11 render: KiCad's
    rotation value in the .kicad_pcb file is mathematical CW (= visually
    CCW with +Y-down screen). With J4 at rotation 90, the stock
    PinHeader_1x05_P1.27mm_Vertical's pin row (native pads at local
    Y = 0..+5.08) was being rotated so pin 5 landed at PCB X = anchor + 5.08
    = -29.21 -- i.e. at the BODY RIGHT EDGE. Pin row spanned X=-34.29
    (pin 1) to X=-29.21 (pin 5), centred at X=-31.75, which is 5.08 mm
    EAST of the LD2410 body's long-axis centerline at X=-36.83. User
    saw this in the render: "te otwory na piny coś uciekły na prawo,
    nie są w osi płytki".
    Fix: J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
    [oas.kicad_pcb]
2026-05-12 kicad: chunk #5c - MIKROE-2462 NFC Tag 2 Click (U4 + C12)
    Final sensors-sub-sheet chunk: the NFC tag connection. Closes the
    last expected ERC hier-label warning (NFC_FD).
    Architecture change vs the v0.6 plan (a discrete NXP NT3H2x11 SMD +
    custom PCB-trace NFC antenna): we instead host the NFC tag on a
    MikroElektronika "NFC Tag 2 Click" (MIKROE-2462) -- NT3H2111 NTAG
    I2C plus + onboard pre-tuned PCB antenna + mikroBUS 2x8 male header.
    The Click board plugs into a 2x8 female pin socket on the OAS PCB
    (P2.54 mm). Pre-tuned antenna eliminates the NXP AN11203 antenna-
    design sub-project entirely; mikroBUS form factor is easy to source
    (TME / Distrelec / Farnell / RS in the EU) and easy to swap o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
    [oas.kicad_sch, sensors.kicad_sch]
2026-05-12 kicad: reserve PCB shadow for ESP32-C6 DevKitM-1 + MIKROE-2462
    User wanted to SEE where the two daughterboards will sit on the OAS
    PCB before chunk #7 (PCB routing) starts. Both modules mount face-up
    on FEMALE pin sockets ("goldpiny żeńskie"), so they sit 3-7 mm above
    the PCB on the standoff. SMD components on the OAS PCB CAN be placed
    UNDER their shadow (within the standoff Z budget).
    Layout (v0.13):
    ESP32-C6 DevKitM-1-N4 (MOD1):
    body 25.4 × 48.26 mm, VERTICAL (long axis along PCB Y)
    anchor (-28.5, -52.5), body X=-28.5..-3.1, Y=-52.5..-4.24
    antenna at TOP short edge (Y=-52.5), USB-C at BOTTOM (Y=-4.24)
    pin rows on long edges at X=-27.23 and X=-4.37
    (2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
    [oas.kicad_pcb]
2026-05-12 kicad: close loose ends - lib stubs + sym-lib-table entry
    Clears the last DRC + ERC warnings that the previous commits left
    dangling.
    1. DRC `lib_footprint_issues` × 2 (cleared):
    Added libraries/oas.pretty/ESP32-C6-DevKitM-1_Reference.kicad_mod
    and libraries/oas.pretty/MIKROE-2462_Reference.kicad_mod -- standalone
    lib copies of the same daughterboard mechanical-reference body that's
    embedded in oas.kicad_pcb. KiCad's footprint-lookup at DRC time now
    finds both, so the "not found in library 'oas'" warning disappears.
    Refactored to share body-content emission between the lib file and
    the placement instance via the new `_daughterboard_body_content()`
    helper, so the tw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
    [generate.py]
2026-05-12 kicad: v0.14 - re-lay daughterboards per verified datasheet dimensions
    User asked for a specific upper-PCB layout AND for me to re-check
    dimensions in vendor documentation instead of guessing. Both done.
    Verified dimensions (with citations):
    - ESP32-C6-DevKitM-1-N4: 25.4 × 48.26 mm. Pin headers 2× 1×15 P2.54 mm,
    row spacing 22.86 mm. Pin block OFFSET 0.98 mm toward the antenna
    short edge: pin 1 sits 5.37 mm in from the antenna edge, pin 15
    sits 7.33 mm in from the opposite (USB-C) edge.
    Source: Espressif dimensions PDF
    https://dl.espressif.com/dl/schematics/esp32-c6-devkitm-1-dimensions.pdf
    - MIKROE-2462 (NFC Tag 2 Click, mikroBUS size S): 25.4 × 28.6 mm
    (NOT 42.9 mm — ear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
    [oas.kicad_pcb]
2026-05-13 kicad: v0.15 - daughterboard re-layout (LD2410 to wall, NFC at LD's Y, ESP32 upper-left)
    - LD2410 ANCHOR_X -34.21 -> -39.66 (body left edge 2.0 mm from PCB outline
    at bottom-left corner Y=+19.05). J4_PCB_X follows: -39.29 -> -44.74.
    - MIKROE-2462 NFC ANCHOR_Y -28.54 -> -13.03 (transverse axis aligned
    with LD2410's at PCB Y=+1.27; +15.51 mm downward shift). NFC antenna
    spiral now at Y=+9.83..+15.57, clear of cable hole.
    - ESP32-C6 ANCHOR_X -24.13 -> -37.16 (LEFT) and ANCHOR_Y -29.54 -> -14.03
    (DOWN as far as NFC top allows, 1 mm gap). Body now at upper-left
    (X=-37.16..+11.10, Y=-39.43..-14.03), antenna short edge at -X (~09:00).
    - DRC=0, ERC=0. Determinism preserved.
    Co-Authored-By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
    [oas.kicad_pcb]
2026-05-13 kicad: v0.15.1 - ESP32 up to edge, NFC tight against LD2410
    - ESP32 ANCHOR_Y -14.03 -> -20.43 (6.40 mm UP). Top-left corner at
    (-37.16, -45.83) sits 1.0 mm from PCB outline (most constraining
    corner; distance to origin = 59.00, outline at 60.0).
    - MIKROE-2462 ANCHOR_X -33.21 -> -38.66 (5.45 mm LEFT). NFC left edge
    now 1.0 mm from LD2410's right edge at X=-39.66. NFC right edge
    (-13.26) leaves 7.26 mm to cable hole.
    - Vertical gap ESP32 bottom -> NFC top now 7.4 mm (was 1.0).
    - DRC=0, ERC=0.
    [oas.kicad_pcb]
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2026-05-13 kicad: v0.15.3 - ESP32 -2/+2 shift, daughterboard silkscreen visible on 3D
    - ESP32 ANCHOR_X -25.76 -> -27.76 (-2 mm LEFT). ANCHOR_Y -26.70 -> -24.70
    (+2 mm DOWN). Body now -27.76..+20.50 / -50.10..-24.70. SEN66
    clearance 3.0 mm (was 1.0); H3 hole clearance 3.0 mm (was 1.0);
    top-corner PCB outline 2.73 mm (was 1.88).
    - Daughterboard mech-ref helper: add F.SilkS body rect (0.2 mm inset)
    and migrate body/antenna/USB text labels from F.Fab -> F.SilkS so
    they're visible on the physical board and 3D render.
    - LD2410 helper: migrate antenna/J4-pins/body labels F.Fab -> F.SilkS.
    Reposition body_label to body center and J4-pins label -8 mm from
    connector edge to keep silk_overlap cleara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
    [oas.kicad_pcb]
2026-05-13 kicad: v0.15.4 - LD2410 silk encloses J4, daughterboard labels specific
    - LD2410_SILK_INSET_CONN: 4.0 -> -1.5. Negative inset extends silk rect
    1.5 mm BEYOND body edge on connector side so the whole J4 footprint
    (pads + stock silk frame + reference text) sits INSIDE the LD2410
    body shadow. Clearance to J4 silk frame: 0.34 mm edge-to-edge.
    - Daughterboard helper: body_label position moved from (body_w/2,
    body_l - 2.5) to body CENTER (body_w/2, body_l/2). Avoids silk_overlap
    when label text width approaches body length (was failing for MIKROE
    with body_l=28.6 and text "MIKROE-2462" rotated 90 extending past
    body bottom).
    - NFC body_label: "NFC" -> "MIKROE-2462" (specific MikroE p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
    [oas.kicad_pcb]
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

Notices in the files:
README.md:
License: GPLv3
